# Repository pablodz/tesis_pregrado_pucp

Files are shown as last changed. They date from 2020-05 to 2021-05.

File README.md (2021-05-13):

# Tesis de Pregrado

[Spanish](https://github.com/ZurMaD/tesis_pregrado_pucp/):
- [T1-Download PDF](https://github.com/ZurMaD/tesis_pregrado_pucp/blob/master/Latex/trabajo-de-investigacion-1/main.pdf)
- [T2-Download PDF](https://github.com/ZurMaD/tesis_pregrado_pucp/blob/master/Latex/trabajo-de-investigacion-2/main.pdf)

## Ambiente de de desarrollo (MikTex+TeXStudio)



## License

<br />This work is licensed under a <a rel="license" href="http://creativecommons.org/licenses/by-nc/4.0/">Creative Commons Attribution-NonCommercial 4.0 International License</a>.

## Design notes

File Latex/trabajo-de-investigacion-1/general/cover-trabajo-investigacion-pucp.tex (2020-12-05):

%----------------------------------------------------------------------------------------
%	Carátula
%----------------------------------------------------------------------------------------
\clearpage{\pagestyle{empty}\cleardoublepage}
\begin{titlepage}
\begin{center}
 {\Large \bf PONTIFICIA UNIVERSIDAD CATÓLICA DEL PERÚ}\\
  \vspace{0.8 cm} 
  {\Large \bf FACULTAD DE CIENCIAS E INGENIERÍA}\\
  \vspace{1.75 cm}
 \begin{figure}[H]
    \centering
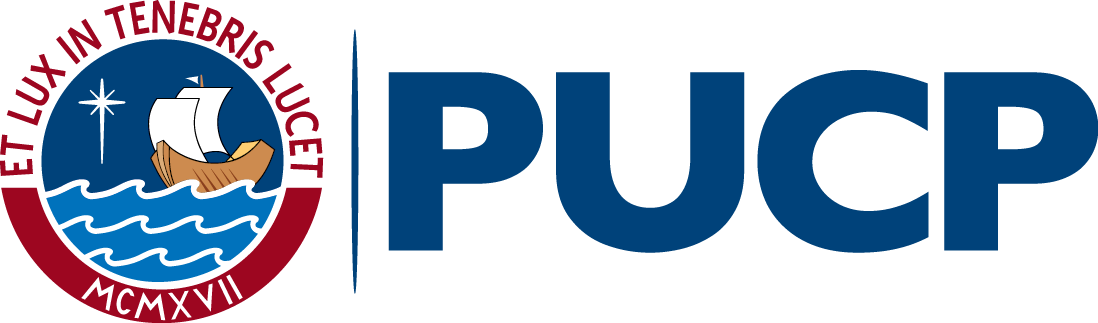
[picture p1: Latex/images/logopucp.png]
    
\end{figure}
  \vspace{0.25cm}

\title{Diseño conceptual de clasificadora y contadora de truchas arcoíris \textit{(Oncorhynchus mykiss)} de 10 a 20 centímetros para la crianza de truchas en la Laguna de Paucarcocha} % titulo de tu tesis para latex
{\Large \bf Diseño conceptual de clasificadora y contadora de truchas arcoíris \textit{(Oncorhynchus mykiss)} de 10 a 20 centímetros para la crianza de truchas en la Laguna de Paucarcocha}\\ % titulo de tu tesis para latex
\vspace{0.5cm}
{\Large \bf TRABAJO DE INVESTIGACIÓN PARA LA OBTENCIÓN DEL GRADO DE BACHILLER EN CIENCIAS CON MENCIÓN EN INGENIERÍA MECATRÓNICA}\\[1.5 cm]
{\large \bf AUTOR}\\[0.5cm]
{\large Pablo Remigio Díaz Vergara}\\[1.25 cm] % nombres del autor o autores
{\large \bf ASESOR}\\[0.5 cm] 
{\large Ing. Pedro Moises Crisóstomo Romero}\\[0.5 cm] % nombre del asesor
\vspace{1.75 cm}
{\large Lima, diciembre, 2019}

\end{center}
\end{titlepage}

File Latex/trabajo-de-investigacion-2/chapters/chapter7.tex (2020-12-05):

%----------------------------------------------------------------------------------------
%	Capítulo 6
%----------------------------------------------------------------------------------------

\pagestyle{myportland}
\doublespacing
%\pagenumbering{arabic}
\chapter[\quad\quad\quad\quad ----- Estimación de costos]{\\ Estimación de costos}
\thispagestyle{myportland}

La estimación de costos del sistema en su conjunto se calcula mediante la separación por rubros específicos. Dichos rubros son relacionados al diseño, manufactura, materiales y dispositivos de uso eléctrico y electrónico.
%% NUEVA SECCIÓN X.X
\section{Costos de diseño}

Este costo está relacionado con la actividad de ingeniería de diseño, se calcula mediante la multiplicación de horas empleadas por el tesista en la redacción, diseño conceptual y diseño de ingeniería con el sueldo mínimo que suele recibir un practicante pre-profesional en el Perú. Las horas empleadas son calculadas por el tesista, el costo es teórico y pretende dar cifras acordes al mercado. En la Tabla \ref{tab:costo de diseno de ingenieria} se detallan los costos asociados mencionados.

\begin{table}[H]
	\footnotesize\centering
	\caption{Costo de diseño de ingeniería.}
	\label{tab:costo de diseno de ingenieria}
	\begin{tabular}{lc|c|c|}
		\hline
		\multicolumn{4}{|c|}{\textbf{Costo de diseño de ingeniería}}  \\ \hline
		\multicolumn{1}{|c|}{\textbf{Concepto}} & \multicolumn{1}{c|}{\textbf{Horas}} & \multicolumn{1}{c|}{\textbf{Costo/hora (S/)}} & \multicolumn{1}{c|}{\textbf{Subtotal (S/)}} \\ \hline
		\multicolumn{1}{|l|}{Diseño conceptual del sistema} & 350 & 9.30 & 3255.00 \\ \hline
		\multicolumn{1}{|l|}{Diseño de ingeniería del sistema} & 350 & 9.30 & 3255.00 \\ \hline
		& & \textbf{Total (S/)} & \textbf{6510.00}  \\ \cline{3-4} 
	\end{tabular}
	\begin{myflushcenteraftertable}	
		Fuente: Elaboración propia.
	\end{myflushcenteraftertable}
\end{table}

%\multicolumn{1}{|l|}{Ensamble del sistema} & A & A & A \\ \hline
%\multicolumn{1}{|l|}{Pruebas del sistema} & A & A & A \\ \hline

%% NUEVA SECCIÓN X.X
\section{Costos de componentes}

Los componentes a considerar son los componentes eléctricos y electrónicos que se emplean para el funcionamiento correcto de la máquina. Los dispositivos son de importación por lo que se aplica un impuesto por importación y gastos de envios en 30\%, con dicha cifra se calcula el costo total. En la Tabla \ref{tab:costo de componentes electricos y electronicos} se exponen de forma detallada los costos unitarios de cada componentes y el total después de envíos e impuestos.

\begin{table}[H]
	\footnotesize\centering
	\caption{Costo de componentes eléctricos y electrónicos.}
	\label{tab:costo de componentes electricos y electronicos}
	\begin{tabular}{llc|c|c|}
		\hline
		\multicolumn{5}{|c|}{\textbf{Costo de componentes eléctricos y electrónicos}} \\ \hline
		\multicolumn{1}{|c|}{\textbf{Componente}} & \multicolumn{1}{c|}{\textbf{Modelo}} & \multicolumn{1}{c|}{\textbf{Costo Unitario (S/)}} & \multicolumn{1}{c|}{\textbf{Cantidad}} & \multicolumn{1}{c|}{\textbf{Subtotal (S/)}} \\ \hline
		\multicolumn{1}{|l|}{Motor a pasos}  & \multicolumn{1}{l|}{NEMA 34} & 78.98 & 2 & 157.96 \\ \hline
		\multicolumn{1}{|l|}{Driver de motor a pasos}  & \multicolumn{1}{l|}{DM860H} & 71.8 & 2 & 143.6 \\ \hline
		\multicolumn{1}{|l|}{Bomba de agua} & \multicolumn{1}{l|}{D03U-DK004X4} & 969.30 & 2 & 1938.6 \\ \hline
		\multicolumn{1}{|l|}{Electroválvula 4''} & \multicolumn{1}{l|}{CTB100} & 287.20 & 1 & 287.20 \\ \hline
		\multicolumn{1}{|l|}{Sensor de presión}  & \multicolumn{1}{l|}{WNK80MA} & 43.08 & 4 & 172.32 \\ \hline
		\multicolumn{1}{|l|}{Sensor infrarrojo}  & \multicolumn{1}{l|}{HD-DS25CM-3MM} & 7.00 & 1 & 7.00 \\ \hline
		\multicolumn{1}{|l|}{Cámara estéreo}  & \multicolumn{1}{l|}{OAK-D} & 475.41 & 1 & 475.41 \\ \hline
		\multicolumn{1}{|l|}{Cámara simple}  & \multicolumn{1}{l|}{OAK-1}& 355.41 & 1 & 355.41 \\ \hline
		\multicolumn{1}{|l|}{LED's de iluminación}  & \multicolumn{1}{l|}{PSH601A} & 17.23 & 1 & 17.23 \\ \hline
		\multicolumn{1}{|l|}{Microprocesador}   & \multicolumn{1}{l|}{Raspberry Pi 4B} & 197.45 & 1 & 197.45 \\ \hline
		\multicolumn{1}{|l|}{Indicador visual}  & \multicolumn{1}{l|}{HS-WS812B-16L-b} & 12.57 & 3 & 37.71 \\ \hline
		\multicolumn{1}{|l|}{Indicador sonoro}  & \multicolumn{1}{l|}{SE-B40} & 35.9 & 1 & 35.9 \\ \hline
		\multicolumn{1}{|l|}{Interruptor de emergencia}  & \multicolumn{1}{l|}{LAY5-JBPN1P} & 21.54 & 1 & 21.54 \\ \hline
		\multicolumn{1}{|l|}{Sensor de iluminación}  & \multicolumn{1}{l|}{-} & 21.36 & 1 & 21.36 \\ \hline
		\multicolumn{1}{|l|}{\begin{minipage}{\mythirdmaxsizeofcontenttable}\begin{myflushleftinsidetable}
					Interruptor de suministro de energía
		\end{myflushleftinsidetable}\end{minipage}}
		&
		\multicolumn{1}{l|}{HEIGHT S/C} & 53.85 & 1 & 53.85 \\ \hline
		\multicolumn{1}{|l|}{Fuente de alimentación}  & \multicolumn{1}{l|}{BNM-24V-500W} & 80.60 & 1 & 80.60 \\ \hline		
		\multicolumn{1}{|l|}{\begin{minipage}{\mythirdmaxsizeofcontenttable}\begin{myflushleftinsidetable}
					Convertidor de voltaje de conmutación
		\end{myflushleftinsidetable}\end{minipage}}
		&
		\multicolumn{1}{l|}{\begin{minipage}{\mythirdmaxsizeofcontenttable}\begin{myflushleftinsidetable}
				WMX-DSD24S1220 y WMX-DSD45S520
		\end{myflushleftinsidetable}\end{minipage}}
		 & 102.78 & 1 & 102.78 \\ \hline
		\multicolumn{1}{|l|}{Placa I2C generador PWM}  & \multicolumn{1}{l|}{PCA9685} & 53.67 & 1 & 53.67 \\ \hline
		\multicolumn{1}{|l|}{Cables} & \multicolumn{1}{l|}{-} & 20 & 1 & 20 \\ \hline
		\multicolumn{1}{|l|}{Activador tipo transistor}  & \multicolumn{1}{l|}{TPN2R304PL} & 0.36 & 4 & 1.44 \\ \hline
		&  &  & \textbf{Subtotal (S/)} & \textbf{5281.03} \\ \cline{4-5} 
		&  &  & \textbf{Impuestos (30\%)} & \textbf{1584.31} \\ \cline{4-5} 
		&  &  & \textbf{Total (S/)} & \textbf{6865.34} \\ \cline{4-5} 
	\end{tabular}
		\begin{myflushcenteraftertable}	
		Fuente: Elaboración propia. \\
		Tasa de cambio de USD a PEN: S/ 3.59.
	\end{myflushcenteraftertable}
\end{table}

%\multicolumn{1}{|l|}{Driver de bomba de agua} & \multicolumn{1}{l|}{B} & B & B & B \\ \hline

Entonces, el costo de todos los componentes sin ensamblar es de S/ 6865.34 incluyendo gastos de envío y traslado de la cantidad específicada en la Tabla \ref{tab:costo de componentes electricos y electronicos}. Este total no debe ser comparado con máquinas comerciales debido a que es el costo de producir una sola máquina y no de producir en lotes, además de no haber pasado por la etapa de prototipado que suele disminuir el precio y perfeccionar el sistema disminuyendo el costo.

%% NUEVA SECCIÓN X.X
\section{Costos de materiales}

Los materiales abarcan las planchas de metal a doblar, las tuberías de plásticos, los perfiles de metal a soldar, los tornillos y refuerzos del sistema. Dichos materiales son listados con su precio comercial actual en los mercados nacionales en la Tabla \ref{tab:costo de materiales estructurales y tuberias}.

\begin{table}[H]
	\footnotesize\centering
	\caption{Costo de materiales estructurales y tuberías}
	\label{tab:costo de materiales estructurales y tuberias}
	\begin{tabular}{llc|c|c|}
		\hline
		\multicolumn{5}{|c|}{\textbf{Costo}} \\ \hline
		\multicolumn{1}{|c|}{\textbf{Material}} & \multicolumn{1}{c|}{\textbf{Descripción}} & \multicolumn{1}{c|}{\textbf{Costo Unitario (S/)}} & \multicolumn{1}{c|}{\textbf{Cantidad}} & \multicolumn{1}{c|}{\textbf{Subtotal}} \\ \hline
		\multicolumn{1}{|l|}{AISI 316} & \multicolumn{1}{l|}{Tubo perfil cuadrado 20x20x5000 mm. (e=2 mm.)} & A & A & A \\ \hline
		\multicolumn{1}{|l|}{AISI 316} & \multicolumn{1}{l|}{Plancha 1x1220x2440 mm.} & 500 & 2 & 1000 \\ \hline
		\multicolumn{1}{|l|}{AISI 316} & \multicolumn{1}{l|}{Plancha 1.5x1220x2440 mm.} & 700 & 1 & 700 \\ \hline
		\multicolumn{1}{|l|}{AISI 316} & \multicolumn{1}{l|}{Plancha 2x1220x2440 mm.} & 850 & 1 & 850 \\ \hline		
		\multicolumn{1}{|l|}{Triplay} & \multicolumn{1}{l|}{Plancha 1x1220x2440 mm.} & 50 & 2 & 100 \\ \hline
		\multicolumn{1}{|l|}{PVC} & \multicolumn{1}{l|}{Tubo 4''x1000 mm.} & 10 & 1 & 10 \\ \hline
		\multicolumn{1}{|l|}{PVC} & \multicolumn{1}{l|}{Tubo 3''x1000 mm.} & 10 & 1 & 10 \\ \hline
		\multicolumn{1}{|l|}{PVC} & \multicolumn{1}{l|}{Tubo Reductor 4-3''} & 5 & 2 & 10 \\ \hline
		\multicolumn{1}{|l|}{PVC} & \multicolumn{1}{l|}{Codo 145 °C 4''} & 3 & 2 & 6 \\ \hline
		\multicolumn{1}{|l|}{PVC} & \multicolumn{1}{l|}{Codo Tipo Y 4''} & 3 & 1 & 3 \\ \hline
		\multicolumn{1}{|l|}{PVC} & \multicolumn{1}{l|}{Codo 90 °C 4''} & 2 & 8 & 16 \\ \hline
		\multicolumn{1}{|l|}{PVC} & \multicolumn{1}{l|}{Codo 145 °C 3''} & 2.5 & 2 & 5 \\ \hline
		\multicolumn{1}{|l|}{PVC} & \multicolumn{1}{l|}{Codo Tipo Y 3''} & 2.2 & 1 & 2.2 \\ \hline
		\multicolumn{1}{|l|}{PVC} & \multicolumn{1}{l|}{Codo 90 °C 3''} & 1.8 & 4 & 7.2 \\ \hline
		\multicolumn{1}{|l|}{AISI 316} & \multicolumn{1}{l|}{Tornillos M4x20} & 0.15 & 18 & 2.70 \\ \hline
		\multicolumn{1}{|l|}{AISI 316} & \multicolumn{1}{l|}{Tornillos M6x60} & 0.20 & 12 & 2.40 \\ \hline
		\multicolumn{1}{|l|}{AISI 316} & \multicolumn{1}{l|}{Tornillos M6x18} & 0.20 & 36 & 7.20 \\ \hline
		\multicolumn{1}{|l|}{AISI 316} & \multicolumn{1}{l|}{Tornillos M8x20} & 0.50 & 16 & 5 \\ \hline
		\multicolumn{1}{|l|}{AISI 316} & \multicolumn{1}{l|}{Tornillos M14x30} & 0.75 & 16 & 12 \\ \hline
		\multicolumn{1}{|l|}{AISI 316} & \multicolumn{1}{l|}{Perno en U 3''} & 0.29 & 2 & 0.58 \\ \hline
		\multicolumn{1}{|l|}{AISI 316} & \multicolumn{1}{l|}{Sujetador sensor infrarrojo} & 3 & 2 & 6 \\ \hline
		\multicolumn{1}{|l|}{Nylon} & \multicolumn{1}{l|}{Cuerdas de sujeción} & 5 & 1 & 5 \\ \hline		
		&  &  & \textbf{Total} & \textbf{2760.28} \\ \cline{4-5} 
	\end{tabular}
	\begin{myflushcenteraftertable}	
		Fuente: Elaboración propia.
	\end{myflushcenteraftertable}
\end{table}

El costo total por concepto de materiales se calcula en S/ 2760.28 y no se le agrega costo de envío ya que todos los materiales listados se pueden conseguir en el mercado nacional, entonces no es necesario ningún incremento en su costo total.

%% NUEVA SECCIÓN X.X
\section{Costos de manufactura}

Los costos de manufactura contemplados en esta sección abarcan únicamente los costos directos de mano de obra, los costos directos de los materiales fueron considerados en la anterior sección y los gastos generales de manufactura están considerados dentro del costo de mano de obra que se presenta en la Tabla debido a que se realiza los servicios por una empresa que brinda los servicios por separado.

\begin{table}[H]
	\footnotesize\centering
	\caption{Costo de manufactura.}
	\label{tab:costo de manufactura}
	\begin{tabular}{l|c|}
		\hline
		\multicolumn{2}{|c|}{\textbf{Costo de mano obra}}  \\ \hline
		\multicolumn{1}{|c|}{\textbf{Concepto}} & \multicolumn{1}{c|}{\textbf{Subtotal (S/)}} \\ \hline
		\multicolumn{1}{|l|}{Servicio de soldadura} & 200.00 \\ \hline
		\multicolumn{1}{|l|}{Servicio de corte láser} & 500.00 \\ \hline
		\multicolumn{1}{|l|}{Servicio de plegado} & 200.00 \\ \hline
		\multicolumn{1}{|l|}{Servicio de mecanizado} & 500.00 \\ \hline
		\multicolumn{1}{|l|}{\textbf{Total (S/)}} &  1400.00 \\ \hline
	\end{tabular}
	\begin{myflushcenteraftertable}	
		Fuente: Elaboración propia.
	\end{myflushcenteraftertable}
\end{table}

%% NUEVA SECCIÓN X.X
\section{Costos total del sistema}

La suma de costos del sistema con las características que se explican en cada sección se calcula alrededor de S/17600.00 ($\approx$\$ 4900.00) que incluye costos de diseño y ensamblaje, componentes eléctricos y electrónicos, materiales y manufactura de un sistema de clasificación y conteo de truchas.

\begin{table}[H]
	\footnotesize\centering
	\caption{Costo total del sistema.}
	\label{tab:costo total del sistema}
	\begin{tabular}{lc|c|c|}
		\hline
		\multicolumn{4}{|c|}{\textbf{Costo del sistema}}  \\ \hline
		\multicolumn{1}{|c|}{\textbf{Concepto}} & \multicolumn{1}{c|}{\textbf{Costo (S/)}} & \multicolumn{1}{c|}{\textbf{Impuestos+Envío (S/)}} & \multicolumn{1}{c|}{\textbf{Subtotal (S/)}} \\ \hline
		\multicolumn{1}{|l|}{Costo de diseño y ensamblaje} & 6510.00 & -- & 6510.00 \\ \hline
		\multicolumn{1}{|l|}{Costo de componentes} & 5281.03 & 1584.31 & 6865.34 \\ \hline
		\multicolumn{1}{|l|}{Costo de materiales} & 2760.28 & -- & 2760.28 \\ \hline
		\multicolumn{1}{|l|}{Costo de manufactura} & 1400.00 & -- & 1400.00 \\ \hline
		& & \textbf{Total (S/)} & \textbf{17535.62}  \\ \cline{3-4} 
	\end{tabular}
	\begin{myflushcenteraftertable}	
		Fuente: Elaboración propia.
	\end{myflushcenteraftertable}
\end{table}

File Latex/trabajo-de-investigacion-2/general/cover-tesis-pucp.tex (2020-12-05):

%----------------------------------------------------------------------------------------
%	Carátula
%----------------------------------------------------------------------------------------
\clearpage{\pagestyle{empty}\cleardoublepage}
\begin{titlepage}
	\begin{center}
		{\Large \bf PONTIFICIA UNIVERSIDAD CATÓLICA DEL PERÚ}\\
		\vspace{0.8 cm} 
		{\Large \bf FACULTAD DE CIENCIAS E INGENIERÍA}\\
		\vspace{1.75 cm}
		\begin{figure}[H]
			\centering
			
		\end{figure}
		\vspace{0.25cm}
		
		\title{Diseño conceptual de clasificadora y contadora de truchas arcoíris \textit{(Oncorhynchus mykiss)} de 10 a 20 centímetros para la crianza de truchas en la Laguna de Paucarcocha} % titulo de tu tesis para latex
		{\Large \bf Diseño integral de clasificadora y contadora de truchas arcoíris \textit{(Oncorhynchus mykiss)} de 10 a 20 centímetros para la crianza de truchas en la Laguna de Paucarcocha}\\ % titulo de tu tesis para latex
		\vspace{0.5cm}
		{\Large \bf TESIS PARA OPTAR POR EL TÍTULO DE BACHILLER EN CIENCIAS CON MENCIÓN EN INGENIERÍA MECATRÓNICA}\\[1.5 cm]
		{\large \bf AUTOR}\\[0.5cm]
		{\large Pablo Remigio Díaz Vergara}\\[1.5 cm] % nombres del autor o autores
		{\large \bf ASESOR}\\[0.5 cm] 
		{\large Ing. Pedro Moises Crisóstomo Romero}\\[0.5 cm] % nombre del asesor
		\vspace{2.0 cm}
		{\large Lima, diciembre, 2020}
		
	\end{center}
\end{titlepage}

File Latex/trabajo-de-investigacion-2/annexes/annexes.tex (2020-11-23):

%----------------------------------------------------------------------------------------
%	Anexos
%----------------------------------------------------------------------------------------

\newpage
%\appendix
\renewcommand{\appendixname}{Anexos}%
\chapter*{\appendixname}

HD-DS25CM-3MM
\href{https://www.adafruit.com/product/2167}{Enlace}
QT50CM
\href{https://www.adafruit.com/product/2168}{Enlace}
GP2Y0A21YK0F
\href{https://www.adafruit.com/product/164}{Enlace}
OAK-D
\href{https://www.arducam.com/oak-opencv-ai-kit-camera/}{Enlace}
B0263
\href{https://www.arducam.com/product/arducam-1mp-stereo-camera-for-raspberry-pi-nvidia-jetson-nano-xavier-nx-dual-ov9281-monochrome-global-shutter-camera-module/}{Enlace}
B0204
\href{https://www.arducam.com/product/b0204-arducam-2mp-global-shutter-ov2311-monochrome-camera-modules-for-raspberry-pi/}{Enlace}
B0249
\href{https://www.arducam.com/product/b0242-arducam-imx477-hq-camera/}{Enlace}
Alvium 1800-U-500m
\href{https://www.edmundoptics.com/p/allied-vision-alvium-1800-u-500m-125-50mp-usb-31-monochrome-camera-board-level/42347/}{Enlace}
CMT-8MP-IMX219-M366
\href{https://github.com/rellimmot/Sony-IMX219-Raspberry-Pi-V2-CMOS}{Enlace}
RPI4B-4GB
\href{https://www.raspberrypi.org/documentation/hardware/raspberrypi/bcm2711/rpi_DATA_2711_1p0_preliminary.pdf
E13446_Tinker_Board_S_UM_WEB}{Enlace}
\href{https://dlcdnets.asus.com/pub/ASUS/mb/Embedded_IPC/TinkerBoard_S/E13446_Tinker_Board_S_UM_WEB.pdf
UFSUB64_E}{Enlace}
\href{https://www.helios.de/web/EN/products/dtsheets_ub64.html}{Enlace}

INDICADOR LUZ NSSW108T NSSW100DT NFSL757GT-V1
\href{https://www.alibaba.com/product-detail/DC24V-smd-lm301b-3030-led-flexible_60785330755.html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}{Enlace}
\href{https://www.alibaba.com/product-detail/Ultra-Bright-SMD-5050-DC-12V_1600057430279.html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}{Enlace}

INDICADOR SONORO SE-B40 SBN151 HMK-69TM
\href{https://spanish.alibaba.com/product-detail/wholesale-cheap-4-5-6-5-inch-2-way-car-audio-speaker-with-tweeter-car-speakers-coaxial-stereo-speaker-for-car-60848556085.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}{Enlace}
\href{https://spanish.alibaba.com/product-detail/1000-watt-powerful-blue-painting-frame-speakers-subwoofer-with-dc-12v-15-inch-speakers-60601667315.html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}{Enlace}
\href{https://spanish.alibaba.com/product-detail/black-12v-car-speakers-6-9-car-speaker-coaxial-car-speaker-hmk-69tm--60292070214.html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}{Enlace}

LED ILUMINACION HS-WS812B-16L-b HS-SK6812-24L-c HS-WS2812B-R16
\href{https://spanish.alibaba.com/product-detail/ws2812b-programable-pixel-led-ring-5v-16leds-rgb-led-ring-lights-60856221694.html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}{Enlace}
\href{https://spanish.alibaba.com/product-detail/addressable-circle-sk6812-ic-built-in-1-8-12-16-24-32-48-60-82-93-rgbw-leds-ring-light-62075774615.html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}{Enlace}
\href{https://spanish.alibaba.com/product-detail/ws2812b-addressable-16-leds-smd5050-rgb-led-angel-eyes-ring-pcb-board-light-1600063580610.html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}{Enlace}

INTERRUPTOR EMERGENCIA LAY5-BS542 LAY5-JBPN1P
\href{https://www.alibaba.com/product-detail/LAY5-BS542-40mm-mushroom-head-emergency_724522258.html}{Enlace}
\href{https://www.alibaba.com/product-detail/LAY5-JBPN1P-single-hole-Button-box_62013768277.html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}{Enlace}
\href{https://www.alibaba.com/product-detail/LAY5-B174H29-push-button-switch-push_60627351782.html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}{Enlace}

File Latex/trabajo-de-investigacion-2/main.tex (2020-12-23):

\include{general/config} % Set page configurations

\begin{document}
	\include{general/cover-tesis-pucp} % Carátula para Tesis
	%\include{general/cover-trabajo-investigacion-pucp}% Carátula para Trabajos de investigación
	\include{general/summary} % Starts roman counter
	\include{general/gratitude} % Agradecimientos (opcional)
	\include{general/table-of-content} % Starts arabic counter
	\include{chapters/before-chapters} % Configuración de páginas
	%\include{chapters/chapter1} % TFC1
	%\include{chapters/chapter2} % TFC1
	%\include{chapters/chapter3} % TFC1	
	\include{general/introduction} 
	\include{chapters/chapter4}
	\include{chapters/chapter5}
	\include{chapters/chapter6}
	\include{chapters/chapter7}
	\include{general/conclusions}
	\include{general/recommendations}
	\include{general/bibliography}
	\include{chapters/after-chapters} % Configuración de páginas
	%\include{annexes/cover-tesis-annexes}
	%\include{annexes/cover-trabajo-investigacion-annexes}% Carátula para Trabajos de investigación
	%\include{annexes/annexes} % No se puede adjuntar pdfs
\end{document}

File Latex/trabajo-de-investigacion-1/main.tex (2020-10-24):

\include{general/config} % Set page configurations

\begin{document}
	%\include{general/cover-tesis-pucp} % Carátula para Tesis
	\include{general/cover-trabajo-investigacion-pucp}% Carátula para Trabajos de investigación
	\include{general/summary} % Starts roman counter
	\include{general/introduction} 
	%\include{general/gratitude} % Agradecimientos (opcional)
	\include{general/table-of-content} % Starts arabic counter
	\include{chapters/before-chapters} % Configuración de páginas
	\include{chapters/chapter1}
	%\include{chapters/chapter2}
	\include{chapters/chapter3}
	\include{general/conclusions}
	%\include{general/recommendations}
	\include{general/bibliography}
	\include{chapters/after-chapters} % Configuración de páginas
	%\include{general/annexes}
\end{document}

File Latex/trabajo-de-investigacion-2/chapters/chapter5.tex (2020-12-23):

%----------------------------------------------------------------------------------------
%	Capítulo 5 
%----------------------------------------------------------------------------------------

\pagestyle{myportland}
%\pagenumbering{arabic}
\doublespacing
\chapter[\quad\quad\quad\quad ----- Diseño mecatrónico integral]{\\ Diseño mecatrónico integral}
\thispagestyle{myportland}

%%%%%%%%%%%%%%%%%%%%%%%%%%%%%%%%%%%%%%%%%%%%%%%%%%%%%%%%%%%%%%
%%%%%                                                    %%%%%
%%%%%             DISEÑO MECATRÓNICO EN SÍ               %%%%%
%%%%%                                                    %%%%%
%%%%%%%%%%%%%%%%%%%%%%%%%%%%%%%%%%%%%%%%%%%%%%%%%%%%%%%%%%%%%%

En este capítulo se realiza el diseño de ingeniería del sistema que abarca la selección de componentes, su distribución eléctrica, electrónica y física. Los cálculos y dimensionamiento asociado a las partes del sistema se desarrollan en este capítulo. Además se realiza una comparación técnica de los componentes acorde a los propósitos de la máquina que finaliza con la selección del componente, mecanismo o algoritmo más apropiado.

\begin{myfigure}[H]
	\footnotesize\centering
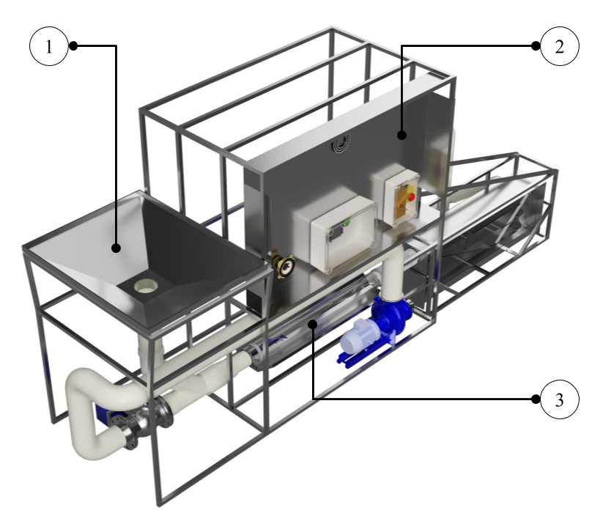
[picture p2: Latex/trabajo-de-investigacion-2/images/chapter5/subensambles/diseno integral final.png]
	
	\caption{Diseño integral de la máquina de clasificación y conteo de truchas.}
	\begin{myflushcenter}
		Leyenda: (1) subsistema de recepción, distribución y traslado de truchas; (2) subsistema de control e interacción con el usuario; (3) subsistema de procesamiento de imágenes.\\
		Fuente: Elaboración propia
	\end{myflushcenter}
	\label{fig:diseno integral}
\end{myfigure}

\vspace{-2.0em}

%% NUEVA SECCIÓN X.X
\section{Descripción del sistema integral}
\label{ssec:descripcion del sistema integral}

Respecto al diseño conceptual, existen algunas modificaciones en los tipos de dispositivos por características técnicas detectadas en el desarrollo de ingeniería del sistema: el cambio del servomotor por un mecanismo de motor a pasos con leva-seguidor que disminuye el desgaste por el sentido de giro; la batería ya no es parte del sistema, el operario debe suministrar la energía necesaria; el adicional de una cámara para el seguimiento de la trayectoria de truchas en el mecanismo de distribución; la variación de el uso de un microcontrolador a microprocesador debido a la potencia computacional requerida; el cambio de bombas sumergibles a bombas de agua por la eficiencia y potencia necesaria en el proyecto\footnote{El precio de las bombas sumergibles sube considerablemente correspondiente a la potencia requerida.}; remoción de la reja al inicio accionada por un motor debido al coste de implementación y reemplazo con un tapón de plástico; cambio de nombre del interruptor de tipo hongo a interruptor de suministro de energía; aumento del máximo peso admisible según requisito a 400 kg. debido al empleo de plataformas flotantes de alta capacidad de flotación en lugar de su uso en botes de 3 metros de largo.

%\textcolor{blue}{[BORRADOR] INGRESAR AQUÍ CAMBIOS REALIZADOS [/BORRADOR]}\\

La máquina clasificadora y contadora de truchas (CCT), y su sistema respectivo tienen como función principal recepcionar truchas mediante una tolva, procesar la clasificación, conteo y distribución hacia tres jaulas flotantes en medio de la Laguna de Paucarcocha.\footnote{\cite{DiazVergara2020}} La máquina se sitúa sobre el agua y es empleada por un operario, que se encarga de extraer truchas con una sacadera telescópica\footnote{También llamada cal-cal.}. En las siguientes páginas se analizan dos puntos generales concernientes al sistema: arquitectura de hardware y la selección de materiales de fabricación por subsistema.

%% NUEVO SUBSECCION X.X.X
\subsection{Arquitectura de hardware}

En la Figura \ref{fig:arquitectura de hardware del sistema} se muestra la propuesta de arquitectura de hardware. Esta arquitectura muestra las entradas de energía del sistema, su redistribución a cada componente, el control asociado a cada pieza mediante el subsistema de control y los protocolos o energía asociado a cada par de bloques. Además, el tipo de conexión se detalla en la leyenda. 

\begin{myfigure}[H]
	\footnotesize\centering
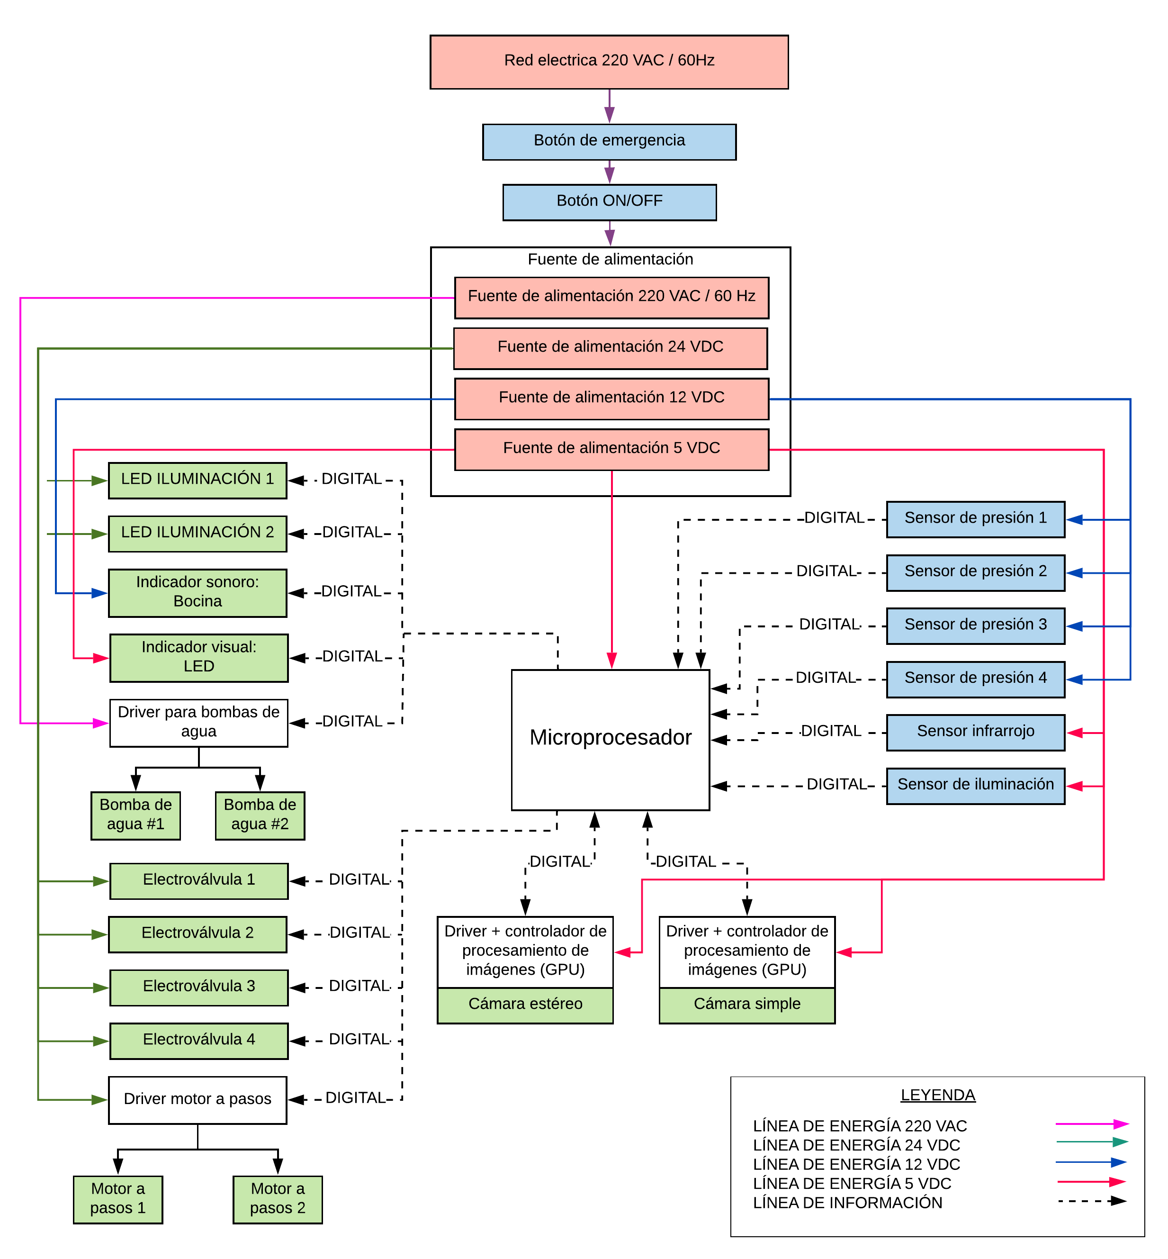
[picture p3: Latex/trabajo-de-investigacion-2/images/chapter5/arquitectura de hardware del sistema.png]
	
	\caption{Arquitectura de hardware del sistema}
	\begin{myflushcenter}
		Fuente: Elaboración propia.
	\end{myflushcenter}
	\label{fig:arquitectura de hardware del sistema}
\end{myfigure}

%% NUEVO SUBSECCION X.X.X
\subsection{Selección de materiales de fabricación}
\label{sssec:seleccion de materiales de fabricacion}

Cada subsistema posee mecanismos que se rigen por un material en general, esto incluye a las partes principales del subsistema. Sin embargo, no considera el material de tornillos, ajustes o dispositivos similares. Existen así mismos requisitos que se pueden generalizar para todos los subsistemas por el entorno de trabajo a la que estará sometida la máquina detallados en la \textit{"Lista de requerimientos"} \footnote{\cite{DiazVergara2020}.}. Basado en dichas demandas, cada subsistema es analizado y presentado con dos alternativas posibles de materiales. Consecuentemente, se elige un material decisivo para ser empleado bajo el sustento técnico que se explicará en los siguientes párrafos.\\

%\begin{itemize}[\null]

\textbf{Subsistema de recepción y traslado de truchas:} Cuenta con dos mecanismos; recepción de truchas y tuberías de traslado. El primero debe recepcionar a las truchas y dirigirlas al mecanismo de tuberías. El segundo debe trasladar a las truchas de un punto a otro de la máquina mediante las tuberías. En la Tabla \ref{tab:tabla comparativa de propiedades entre aluminio vs acero inoxidable} se comparan técnicamente las propiedades mecánicas, térmicas y ópticas de dos materiales.

\begin{mytable}[H]
	\footnotesize\centering
	\caption{Tabla comparativa de propiedades entre $Aluminio$ vs $Acero \quad Inoxidable$}
	\label{tab:tabla comparativa de propiedades entre aluminio vs acero inoxidable}
	\begin{tabular}{|l|c|c|}
		\hline
		\multicolumn{1}{|c|}{\textbf{Propiedad}} & \textbf{Aluminio} & \textbf{Acero Inoxidable} \\ \hline
		Módulo de Young ($GPa$) & 69 & 200 \\ \hline
		Esfuerzo de fatiga $Y$ ($MPa$) & 58-110 & 210-430 \\ \hline
		Resistencia a la tracción ($MPa$) & 130-410 & 520-1180 \\ \hline
		Temperatura máxima mecánica (°$C$) & 650 & 590 \\ \hline
		Conductividad térmica ($W/m-K$) & 170 & 15 \\ \hline
		Expansión térmica (${\mu}m/m-K$) & 24 & 16 \\ \hline
		Conductividad eléctrica ($\%$) & 43 & 2.3 \\ \hline
		Densidad ($g/cm^3$) & 2.7 & 7.9 \\ \hline
	\end{tabular}
	\begin{myflushcenteraftertable}
		*Terminología técnica de los materiales: Aluminio 6061, Acero Inoxidable AISI 306 .\\		
		Fuente: \cite{MakeItFrom2020}.
	\end{myflushcenteraftertable}
\end{mytable}

El material escogido es Aluminio 6061 por tener una densidad menor, facilidad de realizar juntas de soldadura, y aunque tenga menor resistencia mecánica cumple con los requerimientos mínimos asociados al subsistema mencionado.\\

\textbf{Subsistema de procesamiento de imágenes:} Cuenta con los mecanismos de tuberías y juego de espejos. El primero debe brindar a la cámara suficiente transparencia para obtener una fotografía adecuada. El segundo debe brindar a la cámara más perfiles del cuerpo que es trasladado por la tubería. En la Tabla \ref{tab:tabla comparativa de propiedades entre pmma vs pvdf vs petg} se compara técnicamente las propiedades mecánicas, térmicas y ópticas de tres materiales.

\begin{mytable}[H]
	\footnotesize\centering
	\caption{Tabla comparativa de propiedades entre $PMMA$, $PVDF$ y $PETG$}
	\label{tab:tabla comparativa de propiedades entre pmma vs pvdf vs petg}
	\begin{tabular}{|l|c|c|c|}
		\hline
		\multicolumn{1}{|c|}{\textbf{Propiedad}} & \multicolumn{1}{c|}{\textbf{PMMA}} & \textbf{PVDF}& \textbf{PETG} \\ \hline
		Resistencia al impacto: con muescas ($J/m$) & 74 & 180 & 77  \\ \hline
		Expansión térmica (${\mu}m/m-K$)  & 76 & 120 & 68 \\ \hline
		Densidad ($g/cm^3$) & 1.2 & 1.8  & 1.3 \\ \hline
		Resistencia al peso  & 32 & 20 & 25 \\ \hline
		Alargamiento a la rotura ($ \% $) & 4 & 49 & 53 \\ \hline
		Incidencia de luz trasmitida ($ \% $) & 92 & - & - \\ \hline
		Índice de refracción & 1.5 & 1.4 & 1.6\\ \hline			
	\end{tabular}
	\begin{myflushcenteraftertable}
		*Terminología técnica de los materiales: Polimetilmetacrilato (Acrílico)(PMMA), Fluoruro de polivinilideno (PVDF), Tereftalato de polietileno modificado con glicol (PETG).\\		
		Fuente: \cite{Brydson1999,Berins1991,Harper2000,MakeItFrom2020}.
	\end{myflushcenteraftertable}
\end{mytable}

Tanto el PMMA como el PETG tienen menores propiedades mecánicas que PVDF, pero en cuanto a densidad los materiales mencionados son más livianos comparados con el PVDF. En cuanto a las propiedades ópticas, el PMMA tiene un índice de refracción mayor que el PVDF pero menor que el PETG. Sin embargo, la el PMMA es el material más usado en propósitos ópticos comparado con los otros materiales mencionados. El PMMA transparente se puede encontrar en el mercado nacional e internacional por lo que se opta por este material para el subsistema mencionado. En el caso del juego de espejos, las propiedades ópticas son primordiales, por lo que se escoge PMMA.\\

\textbf{Subsistema de procesamiento de suministro de energía y subsistema de control e interacción con el usuario:} Los materiales son propios de los dispositivos electrónicos comerciales dependientes de la tecnología que se selecciona, por lo que se omite una clasificación de materiales en estos subsistemas.\\

%\textbf{:} Los materiales son propios de los dispositivos que serán adquiridos.

\textbf{Subsistema de flotación:} Cuenta con dos mecanismos; armadura y flotadores. El primero debe funcionar como esqueleto para los otros subsistemas y del mismo. El segundo debe mantener el sistema a flote. En la Tabla \ref{tab:tabla comparativa de propiedades entre hdpe vs pvcu} se compara técnicamente las propiedades mecánicas, térmicas y ópticas de dos materiales.

\begin{mytable}[H]
	\footnotesize\centering
	\caption{Tabla comparativa de propiedades entre $HDPE$ vs $PVC-U$}
	\label{tab:tabla comparativa de propiedades entre hdpe vs pvcu}
	\begin{tabular}{|l|c|c|}
		\hline
		\multicolumn{1}{|c|}{\textbf{Propiedad}} & \textbf{HDPE} & \textbf{PVC-U} \\ \hline
		Densidad ($g/cm^3$) & 1.0-1.3 & 1.4 \\ \hline
		Elongación a rotura ($\%$) & 2.5-100 & 58 \\ \hline
		Resistencia al impacto ($J/m$) & 50-260 & 360 \\ \hline
		Resistencia al peso: Flexión & 19-32 & 20 \\ \hline
		Resistencia a la tracción ($MPa$) & 24-80 & 47 \\ \hline
	\end{tabular}
	\begin{myflushcenteraftertable}
		*Terminología técnica de los materiales: Polietileno de alta densidad (HDPE), Cloruro de polivinilo no plastificado (Rígido) (uPVC, PVC-U)\\		
		Fuente: \cite{Brydson1999,Berins1991,Harper2000,MakeItFrom2020}.
	\end{myflushcenteraftertable}
\end{mytable}

En los flotadores es crucial las propiedades mecánicas, ya que en caso de falla puede hundir todo el sistema. La búsqueda de un material con baja densidad, alta resistencia a la tracción, impacto y al peso determinan el material escogido como HDPE. Además dicho material es comercializado nacionalmente e internacionalmente. De forma similar, la armadura debe poseer buenas propiedades mecánicas y por eso se selecciona Acero Inoxidable.\\

%\end{itemize}

Finalmente, en las Tablas \ref{tab:tabla comparativa de propiedades entre aluminio vs acero inoxidable}, \ref{tab:tabla comparativa de propiedades entre pmma vs pvdf vs petg} y \ref{tab:tabla comparativa de propiedades entre hdpe vs pvcu} se comparan diversos materiales para el correspondiente subsistema. Los materiales de fabricación finales para cada subsistema se muestran en la Tabla \ref{tab:materiales de fabricacion por subsistema}, fueron seleccionados por su superioridad en las propiedades técnicas que son valoradas en este proyecto. 

\begin{savenotes}
	\begin{mytable}[H]
		\footnotesize\centering
		\caption{Materiales de fabricación por subsistema}
		\label{tab:materiales de fabricacion por subsistema}
		\begin{tabular}{|l|c|c|}
			\hline
			\multicolumn{1}{|c|}{\textbf{Subsistema}} & \multicolumn{1}{c|}{\textbf{Mecanismo}} & \textbf{Material} \\ \hline
			Recepción y traslado de truchas      & Recepción de truchas   & Aluminio  \\ \hline
			Recepción y traslado de truchas      & Tuberías de traslado   & PVC-U    \\ \hline
			Procesamiento de imágenes            & Tubería                & PMMA  \\ \hline
			Procesamiento de imágenes            & Juego de espejos       & PMMA  \\ \hline
			Suministro de energía                & \multicolumn{1}{c|}{-} & -    \\ \hline
			Control e interacción con el usuario & \multicolumn{1}{c|}{-} & -  \\ \hline
			Flotación                            & Armadura               & Acero Inoxidable \\ \hline
			Flotación                            & Flotadores             & HDPE  \\ \hline
		\end{tabular}
		\begin{myflushcenteraftertable}
		*Terminología técnica de los materiales: Cloruro de polivinilo no plastificado (Rígido) (uPVC, PVC-U), Polimetilmetacrilato ISO 24026-1:2020\footnote{\href{https://www.iso.org/standard/77547.html}{Estándar ISO detallado}. Antecesor: 8257-1:1998. Estándar ASTM: D788-96} (Acrílico) (PMMA), Polietileno de alta densidad (HDPE), Acero Inoxidable AISI 306 , Aluminio 6061 (AL), Fluoruro de polivinilideno (PVDF).\\	
		Fuente: Elaboración propia.
		\end{myflushcenteraftertable}
	\end{mytable}
\end{savenotes}

%% NUEVA SECCIÓN X.X
\section{Repositorios de código fuente}
\label{ssec:repositorio de codigo fuente}

Los códigos de los sistemas, algoritmos y otros se almacenan de forma ordenada en repositorios que permiten el versionado, descentralización y disponibilidad de la información para poder reproducir, editar y mejorar los resultados por otras personas. En la Tabla

\begin{mytable}[H]
	\footnotesize\centering
	\caption{Lista de planos de subensamble.}
	\label{tab:lista de repositorios}
	\begin{tabular}{|l|l|l|}
		\hline
		\multicolumn{1}{|c|}{\textbf{Descripción}} & \multicolumn{1}{c|}{\textbf{Enlace}} & \multicolumn{1}{c|}{\textbf{Demo}} \\ \hline
		\textbf{Plantilla de tesis \LaTeX} & \href{https://github.com/ZurMaD/plantilla_tesis_pucp}{Github} & \href{https://github.com/ZurMaD/plantilla_tesis_pucp/blob/master/plantilla/main.pdf}{PDF} \\ \hline
		\textbf{Presente tesis de pregrado} & \href{https://github.com/ZurMaD/tesis_pregrado_pucp}{Github} & \href{https://github.com/ZurMaD/tesis_pregrado_pucp/blob/master/Latex/trabajo-de-investigacion-2/main.pdf}{PDF}  \\ \hline
		\textbf{Datasets de peces ($\approx$10GB)} & \href{https://github.com/DZPeru/fish-datasets}{Github} & -- \\ \hline		
		\textbf{Algoritmo de medición} & \href{https://github.com/DZPeru/fish-classifier}{Github} & --\\ \hline
		\textbf{Algoritmo de detección y conteo basado en YOLOv3} & \href{https://github.com/DZPeru/fishv3}{Github-Fishv3} & \href{https://fishv3.herokuapp.com/}{Demo-Web} \\ \hline 
		\textbf{Algoritmo de detección y conteo basado en YOLOv4} & \href{https://github.com/DZPeru/fishv4}{Github-Fishv4} & \href{https://fishv4.herokuapp.com/}{Demo-Web}\\ \hline 
		\textbf{Visualización de capas de YOLOv3} & -- & \href{https://netron.app/?url=https://raw.githubusercontent.com/DZPeru/fishv3/master/fishv3/fish_test.cfg}{Visualizador}\\ \hline 
		\textbf{Visualización de capas de YOLOv4} & -- & \href{https://netron.app/?url=https://raw.githubusercontent.com/DZPeru/fishv4/main/fishv4/fish_test.cfg}{Visualizador}\\ \hline 
		\textbf{Prototipo de aplicativo móvil} & -- & \href{https://bit.ly/3ko1nG0}{FigmaDemo}\\ \hline
		\textbf{Simulaciones estructurales} & \href{https://bit.ly/3ohX3ui}{Github} & -- \\ \hline		
	\end{tabular}
	\begin{myflushcenteraftertable}	
		Fuente: Elaboración propia.
	\end{myflushcenteraftertable}
\end{mytable}

\vspace{-2.0em}

%% NUEVA SECCIÓN X.X
\section{Planos del sistema}
\label{ssec:planos del sistema}

Los planos permiten visualizar el sistema de una forma en particular dependiendo del tipo de plano. El código asociado a cada plano indica el tipo de plano, su nivel respecto a la estructura general: ensamble, subensamble o despiece, y el tamaño de página usado para dicho plano. En las Tablas \ref{tab:lista de planos de ensamble y subensamble} y \ref{tab:lista de planos de subensamble} se detalla el código junto con la descripción. Dónde: \textit{E} es Ensamble, \textit{SE} es Subensamble, \textit{D} es despiece, los dígitos seguidos son alfanuméricos que van del 0 a la Z y es su agrupación es similar a la organización en cascada, y finalmente el tamaño de página.\footnote{Por ejemplo: D4587-A3 sería un despiece para el componente que pertenece al subensamble 4000, dentro del dispositivo 0500 y 0080. Además de ser el sétimo componente dentro del dispositivo.}

\vspace{-2.0 em}
%% NUEVO SUBSECCION X.X.X
\subsection{Lista de planos de ensamble}

El plano de ensamble presenta una visión de los diferentes componentes, cómo son las juntas, incluye un listado de componentes y se proporcionan características técnicas como el  tipo de material y cantidad de componentes similares.\footnote{Adaptado de \cite{Goetsch2010}} En la Tabla \ref{tab:lista de planos de ensamble y subensamble} se muestra la lista de planos de ensamble, subensambles y subsubensambles.

\begin{mytable}[H]
	\footnotesize\centering
	\caption{Lista de planos de ensamble y subensamble sistema.}
	\label{tab:lista de planos de ensamble y subensamble}
	\begin{tabular}{|l|l|}
		\hline
		\multicolumn{1}{|c|}{\textbf{Código de Plano}} & \multicolumn{1}{c|}{\textbf{Descripción}} \\ \hline
		\textbf{E1000-A0}         & Ensamble total  \\ \hline
		\textbf{SE1100-A3}        & Subsistema de recepción de truchas  \\ \hline
		\textbf{SE1200-A2}        & Subsistema de distribución de truchas \\ \hline
		\textbf{SE1300-A0}        & Subsistema de traslado de truchas \\ \hline
		\textbf{SE1400-A0}        & Subsistema de procesamiento de imágenes \\ \hline
		\textbf{SE1500-A2}        & Subsistema de control e interacción con el usuario\\ \hline
		\textbf{SE1600-A3}         & Estructura de soporte  \\ \hline
		\textbf{SSE1110-A3}        & Tolva de recepción \\ \hline
		\textbf{SSE1510-A3}        & Panel de control - Caja de control 1\\ \hline
		\textbf{SSE1520-A3}        & Panel de control - Caja de control 2\\ \hline
	\end{tabular}
	\begin{myflushcenteraftertable}	
		Fuente: Elaboración propia.
	\end{myflushcenteraftertable}
\end{mytable}

\vspace{-2.0 em}
%% NUEVO SUBSECCION X.X.X
\subsection{Plano de despiece}

El plano de despiece presenta las características técnicas de cada pieza: muestra dimensiones para poder fabricar la pieza.\footnote{En el presente trabajo se administran, además, subensambles con la finalidad de brindar mayor detalle a cada componente.} En la Tabla \ref{tab:lista de planos de subensamble} se muestra la lista de planos de despiece. 

\begin{mytable}[H]
	\footnotesize\centering
	\caption{Lista de planos de subensamble.}
	\label{tab:lista de planos de subensamble}
	\begin{tabular}{|c|l|}
		\hline
		\multicolumn{1}{|c|}{\textbf{Código de Plano}} & \multicolumn{1}{c|}{\textbf{Descripción}} \\ \hline
		\textbf{D1120-A1}         & Tolva de recepción - Borde \\ \hline
		\textbf{D1130-A3}         & Tolva de recepción - Base de salida \\ \hline
		\textbf{D1211-A1}         & Distribuidora 1:3 - Pared A \\ \hline
		\textbf{D1212-A1}         & Distribuidora 1:3 - Pared B \\ \hline
		\textbf{D1213-A3}         & Distribuidora 1:3 - Tapa de distribuidora \\ \hline
		\textbf{D1214-A3}         & Distribuidora 1:3 - Leva de distribuidora \\ \hline
		\textbf{D1215-A3}         & Distribuidora 1:3 - Lengüeta de salida de tubería \\ \hline
		\textbf{D1216-A3}         & Distribuidora 1:3 - Lengüeta de soporte de servomotor 1 \\ \hline
		\textbf{D1217-A3}         & Distribuidora 1:3 - Lengüeta de soporte de servomotor 2 \\ \hline 
		\textbf{D1218-A3}         & Distribuidora 1:3 - Compuerta mecánica \\ \hline 
		\textbf{D1311-A3}         & Tuberías - Adaptador de entrada de bomba de agua \\ \hline 
		\textbf{D1312-A3}         & Tuberías - Adaptador de salida de bomba de agua \\ \hline 
		\textbf{D1313-A3}         & Tuberías - Adaptador de electroválvula\\ \hline
		\textbf{D1413-A3}         & Procesamiento de imágenes - Soporte de cámara estéreo \\ \hline
		\textbf{D1414-A2}         & Procesamiento de imágenes - Soporte de espejos \\ \hline
		\textbf{D1501-A3}         & Panel de control - Soporte \\ \hline
	\end{tabular}
	\begin{myflushcenteraftertable}	
		Fuente: Elaboración propia.
	\end{myflushcenteraftertable}
\end{mytable}

\vspace{-2.0 em}

%----------------------------------------------------------------------------------------
%	Capítulo 5 
%----------------------------------------------------------------------------------------
%\pagestyle{myportland}
%\pagenumbering{arabic}
%\doublespacing
%\chapter[\quad\quad\quad\quad ----- Diseño de subsistema de flotación]{\\ Diseño de subsistema de flotación}
%\thispagestyle{myportland}
%\label{ssec:diseno de subsistema de flotacion}

\section{Subsistema de flotación}

Luego de definir en las secciones anteriores los componentes a utilizar y su interacción con el sistema, es momento de calcular las dimensiones de la máquina para analizar la flotabilidad y seleccionar flotadores adecuados. En las siguientes subsecciones se analizan los cálculos, selección y diseño del sistema de flotación.% En la Figura \ref{fig:subsistema de flotacion} se enumera los componentes principales: 

\begin{myfigure}[H]
	\footnotesize\centering
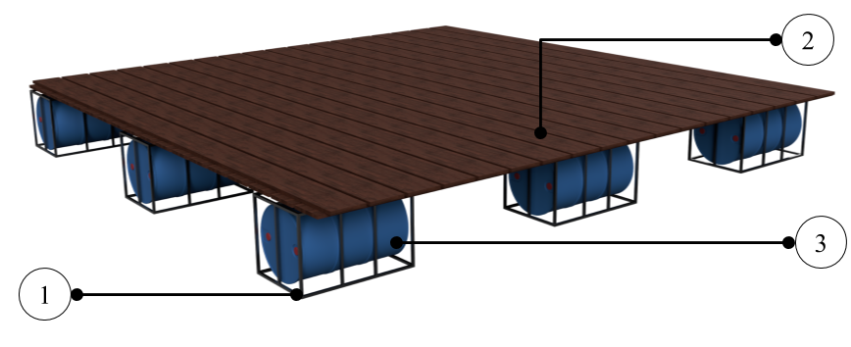
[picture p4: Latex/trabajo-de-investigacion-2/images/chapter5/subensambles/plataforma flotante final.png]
	
	\caption{Subsistema de flotación}
	\begin{myflushcenter}
		Leyenda: (1) armadura de cilindro de flotación; (2) superficie de madera y marco de metal interior; (3) cilindro de flotación.\\
		Fuente: Elaboración propia.
	\end{myflushcenter}
	\label{fig:subsistema de flotacion}
\end{myfigure}

\vspace{-2.0em}

%% NUEVO SECCION X.X.X.
\subsection{Sistema para mantener a flote el sistema}

La plataforma flotante de 5x5 m. que se muestra en la Figura \ref{fig:subsistema de flotacion} es empleada por las empresas en el sector de crianza de truchas en lagunas por su flotabilidad y área útil que brinda a los operarios. En el caso de la CCT, ocupa un área pequeña de 2.5x1m pero con un peso aproximado de 260 kg. Por lo que, como se muestra en la Figura \ref{fig:refuerzo subsistema de flotacion}, se agregan refuerzos para evitar que la CCT se desplace libremente.

\begin{myfigure}[H]
	\footnotesize\centering
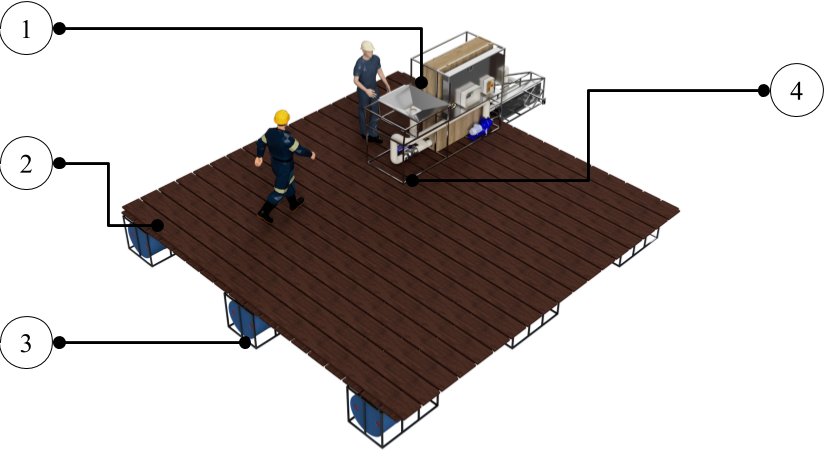
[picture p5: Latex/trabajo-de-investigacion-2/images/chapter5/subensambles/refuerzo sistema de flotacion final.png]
	
	\caption{Fuerzas necesarias para mantener a flote el sistema}
	\begin{myflushcenter}
		Fuente: Elaboración propia.
	\end{myflushcenter}
	\label{fig:refuerzo subsistema de flotacion}
\end{myfigure}

En la Figura \ref{fig:refuerzo subsistema de flotacion} se enumeran los principales elementos: 1. Máquina CCT; 2. Plataforma de madera con refuerzo de marco de acero interior; 3. cilindros con armazón que sirven de flotación; 4. Lugares de refuerzo para fijación a la plataforma de madera. Cabe resaltar que en el presente trabajo no se considera el sistema de flotación dentro del presupuesto, sino que sirve de manera expositiva sobre cómo es que funciona y de qué materiales usualmente está hecho, esto se expone debido a que la problemática se desarrolla en la Laguna de Paucarcocha y usualmente las empresas de producción acuícola poseen este tipo de plataformas que les sirve para otros procesos como los de repartir comida o realizar procesos manuales.

%----------------------------------------------------------------------------------------
%	Capítulo 5 
%----------------------------------------------------------------------------------------

\pagestyle{myportland}
%\pagenumbering{arabic}
\doublespacing
\chapter[\quad\quad\quad\quad ----- Diseño de subsistema de recepción, distribución y traslado de truchas]{\\ Diseño de subsistema de recepción, distribución y traslado de truchas}
\thispagestyle{myportland}

\label{ssec:diseno de subsistema de recepcion, distribucion y traslado de truchas}

Este subsistema consiste en encapsular los mecanismos físicos que están en el ciclo que sigue una trucha dentro de la máquina: tolva, tuberías, bomba de agua, distribución física por mecanismos, caudales apropiados y el control respectivo. Los puntos mencionados se detallan en las siguientes páginas. % En la Figura \ref{fig:subsistema de recepción, distribución y traslado de truchas} se muestran los tres sistemas: 

\begin{myfigure}[H]
	\footnotesize\centering
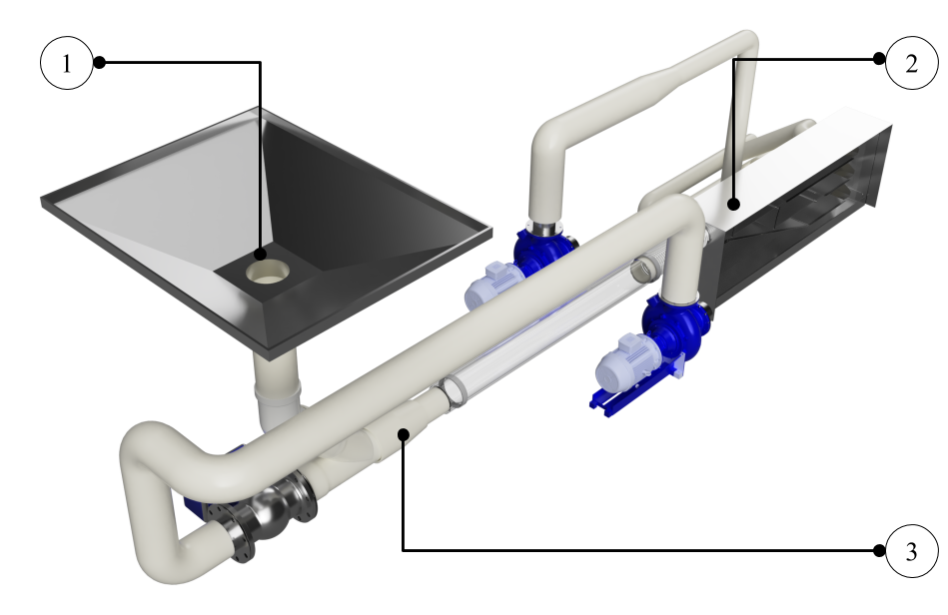
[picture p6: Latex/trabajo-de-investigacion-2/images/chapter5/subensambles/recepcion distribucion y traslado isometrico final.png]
	
	\caption{Subsistema de recepción, distribución y traslado de truchas}
	\begin{myflushcenter}
		Leyenda: Subsistemas de (1) recepción; (2) distribución; (3) distribución.\\
		Fuente: Elaboración propia.
	\end{myflushcenter}
	\label{fig:subsistema de recepción, distribución y traslado de truchas}
\end{myfigure}

\vspace{-2.0em}

%% NUEVO SECCION X.X.
\section{Diseño del subsistema de recepción de truchas}

El subsistema de recepción de truchas se encarga de únicamente a recopilar las truchas mediante una tolva como se muestra en la Figura \ref{fig:subsistema de recepcion}.

\begin{myfigure}[H]
	\footnotesize\centering
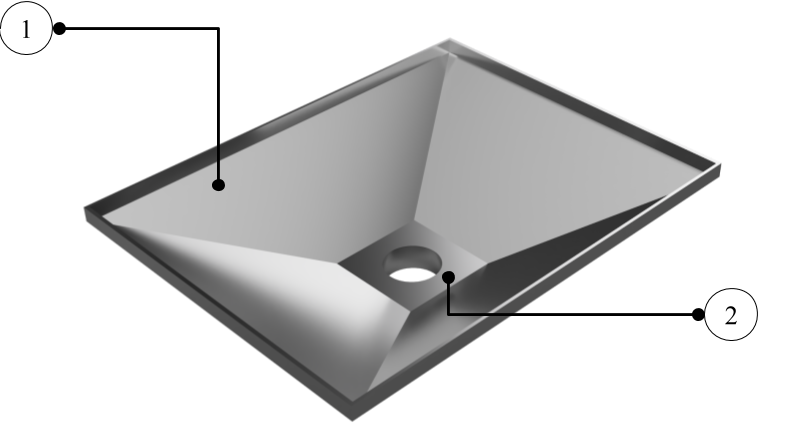
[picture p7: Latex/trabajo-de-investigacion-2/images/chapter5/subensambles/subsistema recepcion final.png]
	
	\caption{Mecanismo de distribución de truchas}
	\begin{myflushcenter}
		Leyenda: (1) borde de tolva; (2) base de tolva. \\
		Fuente: Elaboración propia.
	\end{myflushcenter}
	\label{fig:subsistema de recepcion}
\end{myfigure}
\vspace{-2.0em}

%% NUEVO SECCION X.X.X
\subsection{Cálculos dimensiones del subsistema de recepción de truchas}

El diseño implica un análisis sobre las situaciones que suceden cuando se realiza el proceso de depositar las truchas. En la Figura \ref{fig:calculo de dimensiones y angulo de la tolva} se analiza dicha situación con la finalidad de escoger un ángulo de elevación de la tolva ($\beta$) adecuado. Respecto a la tolva, se designan los siguientes valores iniciales: $A_{min},B_{min}=200 mm.$; $\beta \in [0;45] ^\circ$; ${tolva}=150 mm.$. Además, debe cumplirse que $A_{max}>B_{max}$ orientado hacia el operario que depositará la trucha.

\begin{myfigure}[H]
	\footnotesize\centering
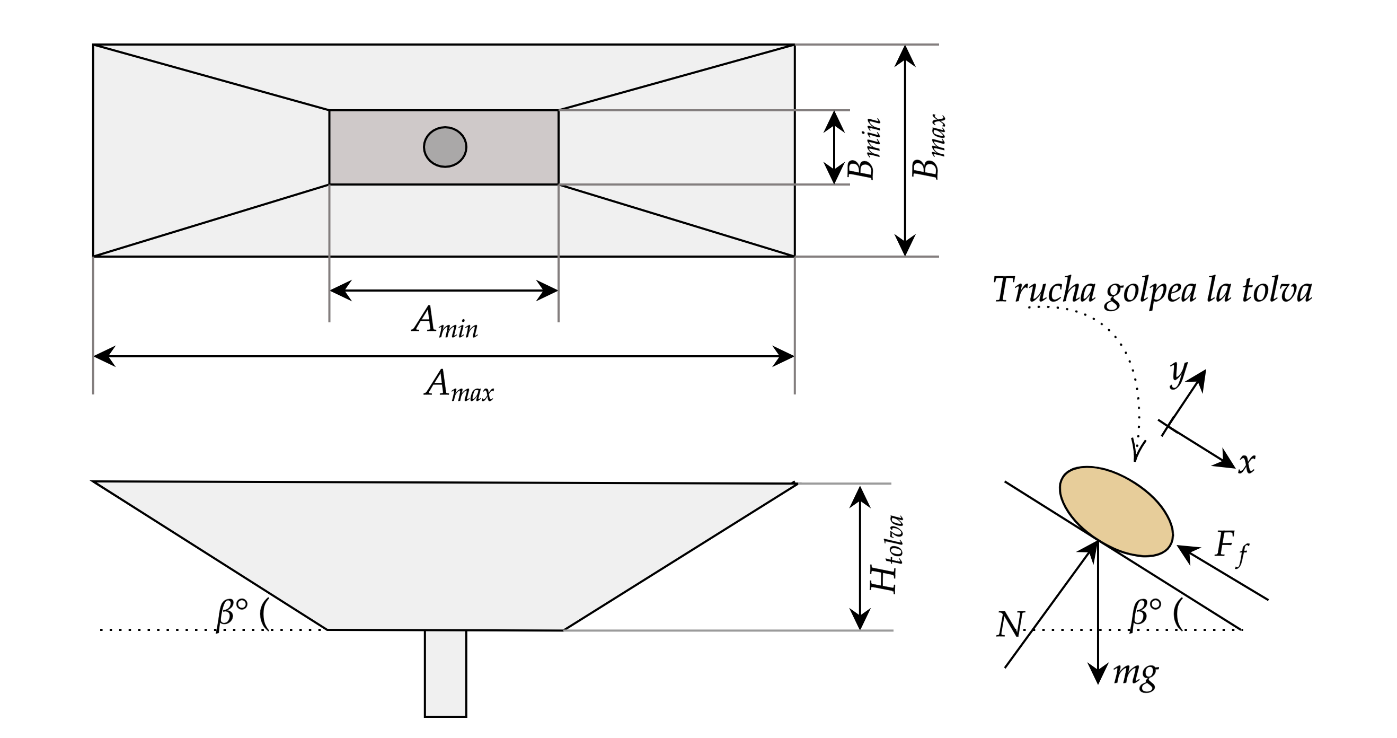
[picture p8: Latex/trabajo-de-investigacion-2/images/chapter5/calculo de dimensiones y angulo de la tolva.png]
	
	\caption{Cálculo de dimensiones y ángulo de la tolva}
	\begin{myflushcenter}
		Fuente: Elaboración propia.
	\end{myflushcenter}
	\label{fig:calculo de dimensiones y angulo de la tolva}
\end{myfigure}

Parte de la Figura \ref{fig:calculo de dimensiones y angulo de la tolva} muestra el diagrama de cuerpo libre del cual se extrae la fuerza de fricción ($F_{f}$) y la fuerza normal ($N$) que se muestran en la Ecuación \ref{eq:calculo de angulo de la tolva}. Las leyes de Newton se muestran en la Ecuación \ref{eq:leyes de newton}. 

\begin{myequation}\label{eq:leyes de newton}
	\begin{split}
		F_{R}=m*a \\
		\sum_{0}^{n}F_{x,y,z}=0
	\end{split}
\end{myequation}

\begin{myequation}\label{eq:calculo de angulo de la tolva}
	\begin{split}
		F_{f}=\mu*N  \\
		\sum_{}^{}F_{y}=N-mg*cos(\beta)=0
	\end{split}
\end{myequation}

Luego, se reemplazan la Ecuación \ref{eq:calculo de angulo de la tolva} en la Ecuación \ref{eq:leyes de newton} y se obtiene la Ecuación \ref{eq:calculo de angulo de la tolva2}. La variable a despejar es la aceleración en el eje x ($\ddot{x}$).

\begin{myequation}\label{eq:calculo de angulo de la tolva2}
	\begin{split}
		mg*sin(\beta)-F_{f}&=m*\ddot{x} \\
		mg*sin(\beta)-\mu_{k}*mg*cos(\beta)&=m*\ddot{x} \\
		g*sin(\beta)-g*\mu_{k}*cos(\beta)&=\ddot{x}
	\end{split}
\end{myequation}

Para disminuir el impacto de la trucha sobre la tolva o sobre las tuberías interiores se debe disminuir la aceleración de la trucha al ser depositada en la tolva. La Figura \ref{fig:grafico angulo de tolva vs aceleracion} muestra la ecuación que relaciona la aceleración con el ángulo de elevación de la pared de la tolva. Consecuentemente, se escoge un ángulo ($\beta=30^\circ$) para tener una aceleración aproximadamente nula ($\ddot{x}\approx0$). Se considera $\mu_{k}=0.57$ para el material escogido en la sección \ref{sssec:seleccion de materiales de fabricacion}. Consecuentemente, se calculan los valores de $A_{max}\approx{900} mm.$ y $B_{max}\approx{700} mm.$, respectivamente.

% Material escogido Acero inoxidable

\begin{myfigure}[H]
	\footnotesize\centering
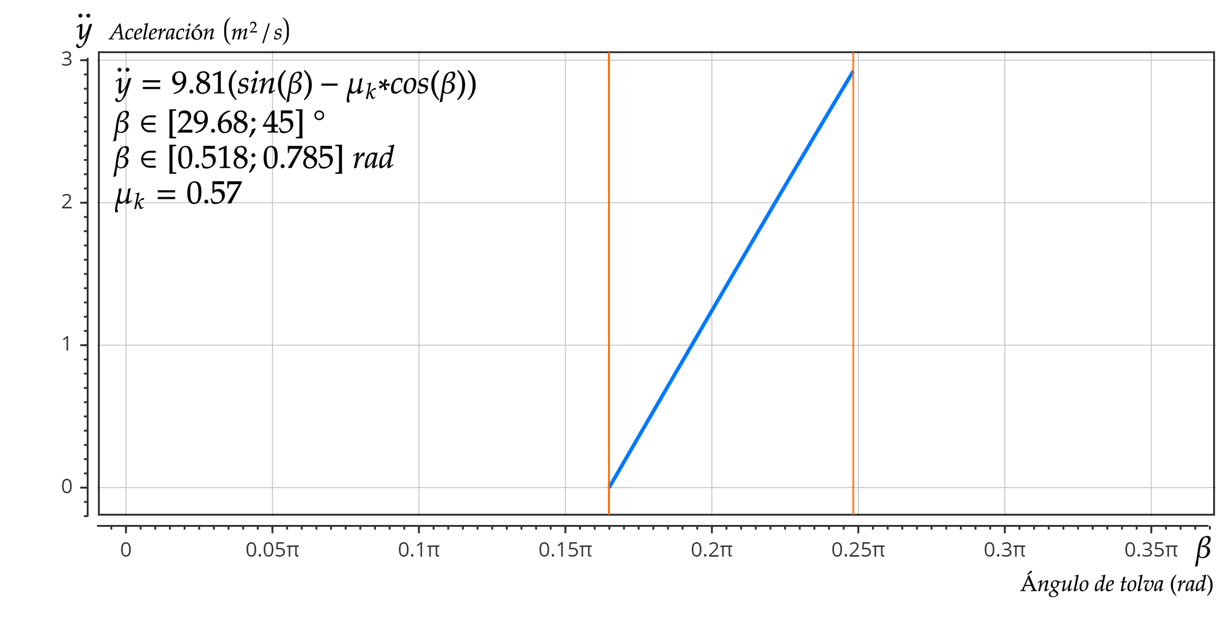
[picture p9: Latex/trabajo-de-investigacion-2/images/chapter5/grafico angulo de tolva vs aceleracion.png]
	
	\caption{Ángulo de tolva vs aceleración en la trucha}
	\begin{myflushcenter}
		Fuente: Elaboración propia.
	\end{myflushcenter}
	\label{fig:grafico angulo de tolva vs aceleracion}
\end{myfigure}

\vspace{-2.0em}

%% NUEVO SECCION X.X.
\section{Diseño de subsistema de distribución de truchas}

Luego del proceso de procesamiento de imágenes el sistema mediante el algoritmo de clasificación indica al sistema la trayectoria que debe seguir la trucha en tránsito y es accionado por el mecanismo de distribución, mostrado en las Figuras \ref{fig:mecanismo de distribucion de truchas} y \ref{fig:mecanismo de distribucion de truchas2}. Dicho mecanismo recibe a la trucha por una única entrada y redirige mediante un juego de compuertas a tres salidas. Finalmente, las truchas son impulsadas al ingresar a tuberías con caudal de agua constante que las transporta hasta las jaulas flotantes correspondientes.

\begin{myfigure}[H]
	\footnotesize\centering
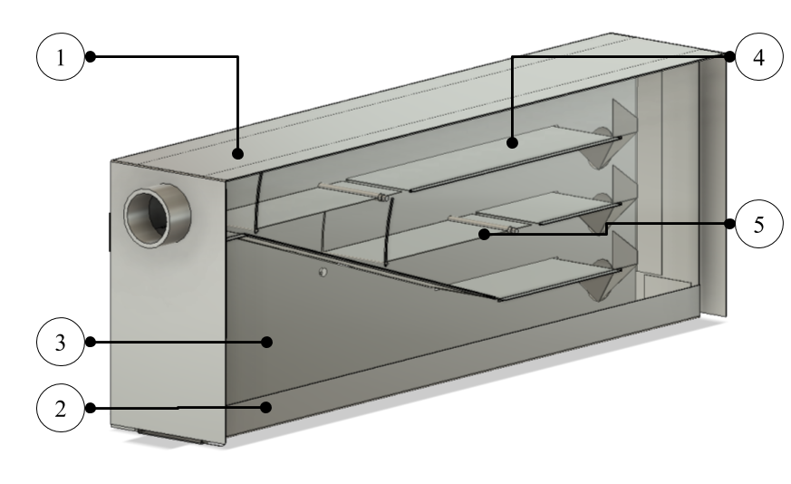
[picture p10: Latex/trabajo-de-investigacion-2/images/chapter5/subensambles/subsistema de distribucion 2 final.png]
	
	\caption{Mecanismo de distribución de truchas - Vista isométrica}
	\begin{myflushcenter}
		Leyenda: (1) placa tipo tapa; (2) pared a de la distribuidora; (3) pared b de la distribuidora; (4) placa intermedia; (5) mecanismo de compuerta\footnote{La leva no se muestra adecuadamente en esta vista.} \\
		Fuente: Elaboración propia.
	\end{myflushcenter}
	\label{fig:mecanismo de distribucion de truchas}
\end{myfigure}

\begin{myfigure}[H]
	\footnotesize\centering
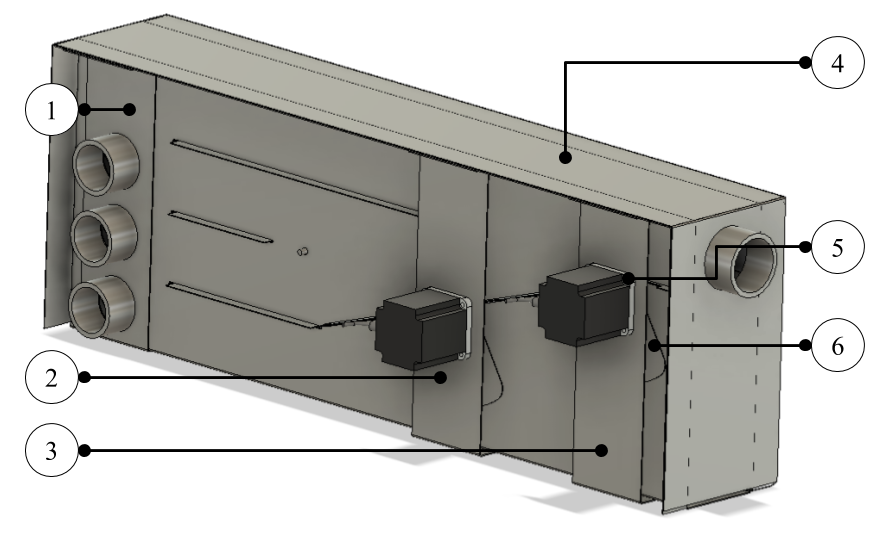
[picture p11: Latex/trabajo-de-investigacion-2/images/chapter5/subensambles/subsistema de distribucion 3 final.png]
	
	\caption{Mecanismo de distribución de truchas - Vista isométrica opuesta}
	\begin{myflushcenter}
		Leyenda: (1) lengüeta de salida; (2) lengüeta de servomotor 2; (3) lengüeta de servomotor 1; (4) placa tipo tapa; (5) servomotor; (6) leva.\\
		Fuente: Elaboración propia.
	\end{myflushcenter}
	\label{fig:mecanismo de distribucion de truchas2}
\end{myfigure}

\vspace{-2.0em}

%% NUEVO SECCION X.X.X.
\subsection{Selección de mecanismo que acciona la compuerta}
	
La selección del mecanismo que activa la compuerta tiene requisitos técnicos que son muy importantes, de no funcionar puede parar completamente el proceso general, por lo que se realiza una comparación de los posibles mecanismos a utilizar para hacer girar la compuerta de manera cíclica ordenado por el subsistema de control. La comparación conceptual se muestra en la Tabla \ref{tab:tabla comparativa de conceptos de mecanismos para compuerta} y los conceptos de mecanismos analizados se muestran en la Figura \ref{fig:conceptos de mecanismos de distribucion de truchas}.
	
\begin{myfigure}[H]
	\footnotesize\centering
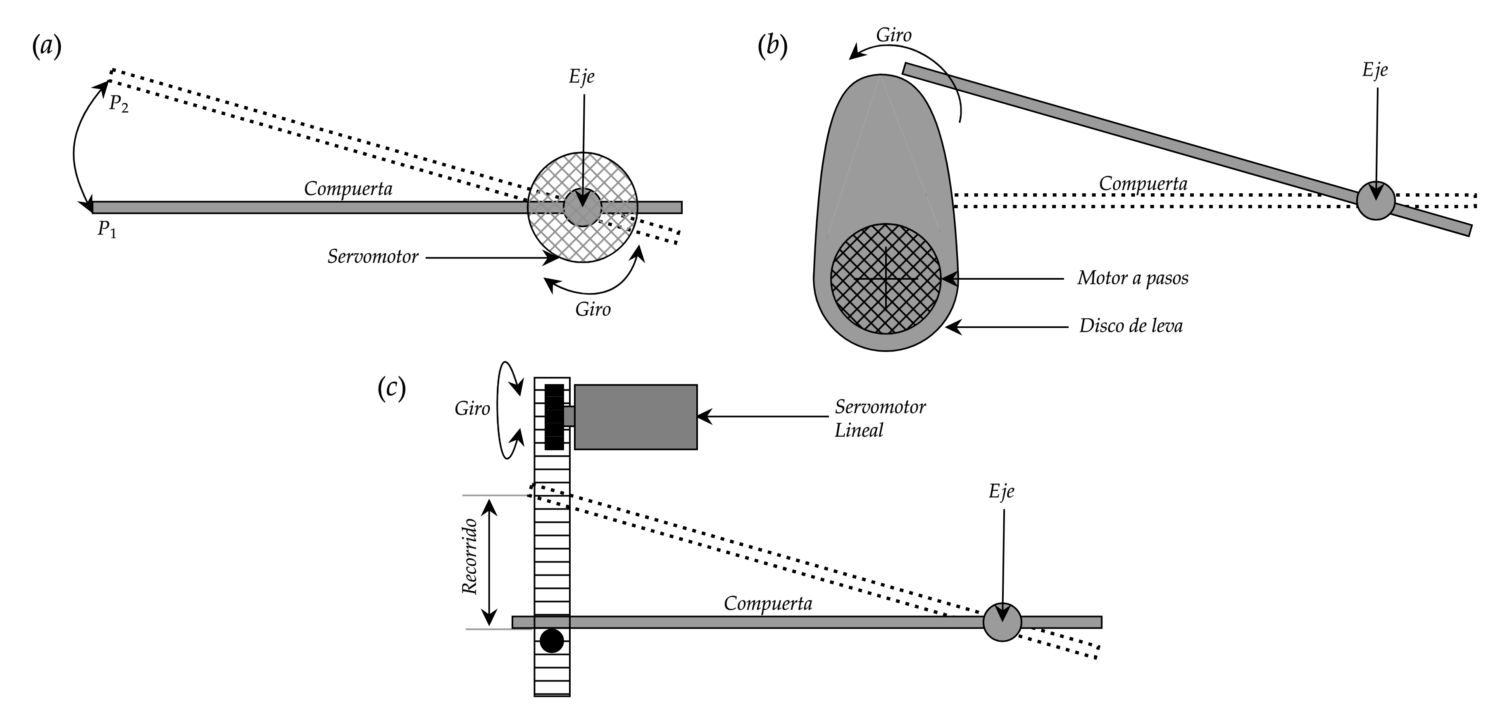
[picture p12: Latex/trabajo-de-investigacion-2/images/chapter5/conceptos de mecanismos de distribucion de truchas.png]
	
	\caption[Conceptos de mecanismos de distribución de truchas]{(a) Mecanismo de eje servomotor. (b) Mecanismo de tolva y seguidor. (c) Mecanismo de servomotor lineal.}
	\begin{myflushcenter}
		Fuente: Elaboración propia.
	\end{myflushcenter}
	\label{fig:conceptos de mecanismos de distribucion de truchas}
\end{myfigure}
	
El mecanismo inicialmente propuesto (Figura \ref{fig:conceptos de mecanismos de distribucion de truchas}-a) corresponde a un servomotor conectado al eje de la compuerta del sistema de distribución, los apoyos no son representados en las figuras. El sistema, al efectuar cierta cantidad de giros en un periodo largo\footnote{Una jornada diaria de clasificación puede someter al mecanismo a abrir/cerrar la compuerta en $t_{compuerta}\approx1 s.$ durante $t_{jornadaxdia}=6 h.$} presenta un deterioro considerable en el eje del servomotor, por lo que se analiza un mecanismo de leva-seguidor (Figura \ref{fig:conceptos de mecanismos de distribucion de truchas}-b) que traslada el giro fuera del eje, en un solo sentido y se aplica el giro sobre un extremo de la compuerta, el disco de leva está posicionado para brindar un movimiento armónico al extremo de la compuerta. Así también, se considera un mecanismo de servomotor lineal que mediante una traba en la cremallera desplaza la compuerta hasta la posición requerida mediante giros en los dos sentidos.

\begin{savenotes}	
	\begin{mytable}[H]
		\footnotesize\centering
		\caption{Tabla comparativa de conceptos de mecanismos.}
		\label{tab:tabla comparativa de conceptos de mecanismos para compuerta}
		\begin{tabular}{l|c|c|c|c|}
			\cline{2-5}
			\multicolumn{1}{c|}{\textbf{}} & 
			\textbf{\begin{tabular}[c]{@{}c@{}}Requisitos\\ mínimos\end{tabular}} & \begin{minipage}{\mythirdmaxsizeofcontenttable}\begin{myflushcenterinsidetable}
					\textbf{Servomotor de rotación posicional}
			\end{myflushcenterinsidetable}\end{minipage} & 
			\begin{minipage}{\mythirdmaxsizeofcontenttable}\begin{myflushcenterinsidetable}
					\textbf{Leva y seguidor}
			\end{myflushcenterinsidetable}\end{minipage} &
			\begin{minipage}{\mythirdmaxsizeofcontenttable}\begin{myflushcenterinsidetable}
					\textbf{Servomotor lineal}
			\end{myflushcenterinsidetable}\end{minipage} \\ \hline
			%\multicolumn{1}{|l|}{\textbf{Figura}} & - & 
			%Figura \ref{fig:conceptos de mecanismos de distribucion de truchas}-a &
			%Figura \ref{fig:conceptos de mecanismos de distribucion de truchas}-b &
			%Figura \ref{fig:conceptos de mecanismos de distribucion de truchas}-c \\ \hline
			\multicolumn{1}{|l|}{
				\begin{minipage}{\myforthmaxsizeofcontenttable}			
					\textbf{Cantidad de sentidos de giro}
				\end{minipage}
			} & 1 & 2 & 1 & 2 \\ \hline
			\multicolumn{1}{|l|}{
				\begin{minipage}{\myforthmaxsizeofcontenttable}			
					\textbf{Complejidad mecánica\footnote{Basado en cantidad de componentes actuadores.}}
				\end{minipage}
			} & 1 & 1 & 2 & 2 \\ \hline
			\multicolumn{1}{|l|}{
				\begin{minipage}{\myforthmaxsizeofcontenttable}			
					\textbf{Disponibilidad en el mercado\footnote{Basado en el componente más "difícil" de conseguir.Calificación cualitativa: nacional o internacional}}
				\end{minipage}
			} & - & Nacional & Internacional & Nacional \\ \hline
			\multicolumn{1}{|l|}{
				\begin{minipage}{\myforthmaxsizeofcontenttable}			
					\textbf{Torque máximo\footnote{Basado en situación crítica encontrada derivando la ecuación de torque respectivo. Dónde: $d_{eje}$ es la distancia del centro de gravedad de la compuerta al eje, $d_{leva}$ es la distancia del centro del disco de leva hasta la parte más alejada de este y $d_{ser}$ es diámetro del engranaje en el mecanismo piñón-cremallera del servomotor lineal. ($d_{ser}<d_{leva}<d_{eje}$)} ($\overrightarrow{\tau_{max}}$)}	
				\end{minipage}
			} & - & $\approx m*g*d_{eje}$ & $\approx m*g*d_{leva}/2$ & $\approx m*g*d_{ser}/4$ \\ \hline
			%\multicolumn{1}{|l|}{
			%	\begin{minipage}{\myforthmaxsizeofcontenttable}			
			%		\textbf{Desgaste\footnote{Calificación cualitativa: bajo, medio o alto.}}
			%	\end{minipage}
			%} & - & Alto & Bajo & Medio \\ \hline
			\multicolumn{1}{|l|}{
				\begin{minipage}{\myforthmaxsizeofcontenttable}			
					\textbf{Acoplamiento al sistema\footnote{Basado en cantidad de componentes adicionales necesarios para implementar. }}
				\end{minipage}
			} & 1 & 1 & 2 & 3 \\ \hline
			\multicolumn{1}{|l|}{
				\begin{minipage}{\myforthmaxsizeofcontenttable}			
					\textbf{Actuador que genera ruido\footnote{Componente que genera sonido.}}
				\end{minipage}
			} & - & Servomotor rotatorio & Motor a pasos & Servomotor lineal \\ \hline
		\end{tabular}
		\begin{myflushcenteraftertable}	
			Fuente: Elaboración propia.
		\end{myflushcenteraftertable}
	\end{mytable}
\end{savenotes}	

El mecanismo escogido es el leva y seguidor ya que solo es necesario su giro en un sentido, lo cual disminuye el desgaste, se acopla al sistema sin implementar más soportes que los otros mecanismos, no genera ruido y su fabricación, en caso no se encuentre en el mercado peruano, se puede realizar en un taller nacional.  	

%% NUEVO SECCION X.X.X.
\subsection{Diseño de mecanismo que acciona la compuerta}
	
En cuanto al mecanismo determinado, se realiza una análisis simple para determinar la forma que tendrá el disco de leva (\ref{fig:mecanismo compuerta}-b) y con ese fin se realiza un diagrama de cuerpo libre (\ref{fig:mecanismo compuerta}-a) que permite analizar las fuerzas sobre los cuerpos.

\begin{myfigure}[H]
	\footnotesize\centering
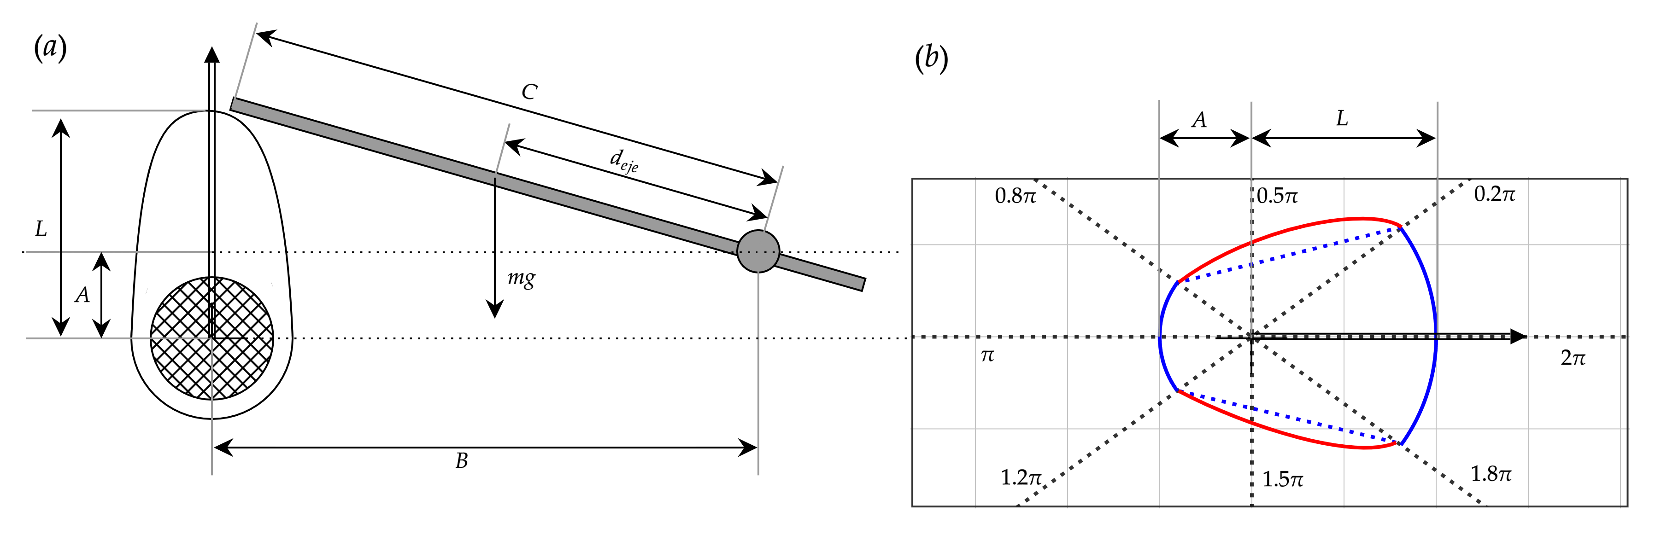
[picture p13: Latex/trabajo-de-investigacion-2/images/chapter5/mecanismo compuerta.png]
	
	\caption[Mecanismo leva-seguidor]{(a) Diagrama de cuerpo libre de mecanismo leva-seguidor. (b) Dimensiones del disco de leva.}
	\begin{myflushcenter}
		Fuente: Elaboración propia.
	\end{myflushcenter}
	\label{fig:mecanismo compuerta}
\end{myfigure}

El diseño del disco de leva que se muestra en la Figura \ref{fig:mecanismo compuerta}-b corresponde al posicionamiento requerido (línea azul) y a un posicionamiento óptimo (línea roja). Dicho posicionamiento versus el ángulo de giro se muestra en la Figura \ref{fig:mecanismo compuerta leva posicionamiento}. 

\begin{myfigure}[H]
	\footnotesize\centering
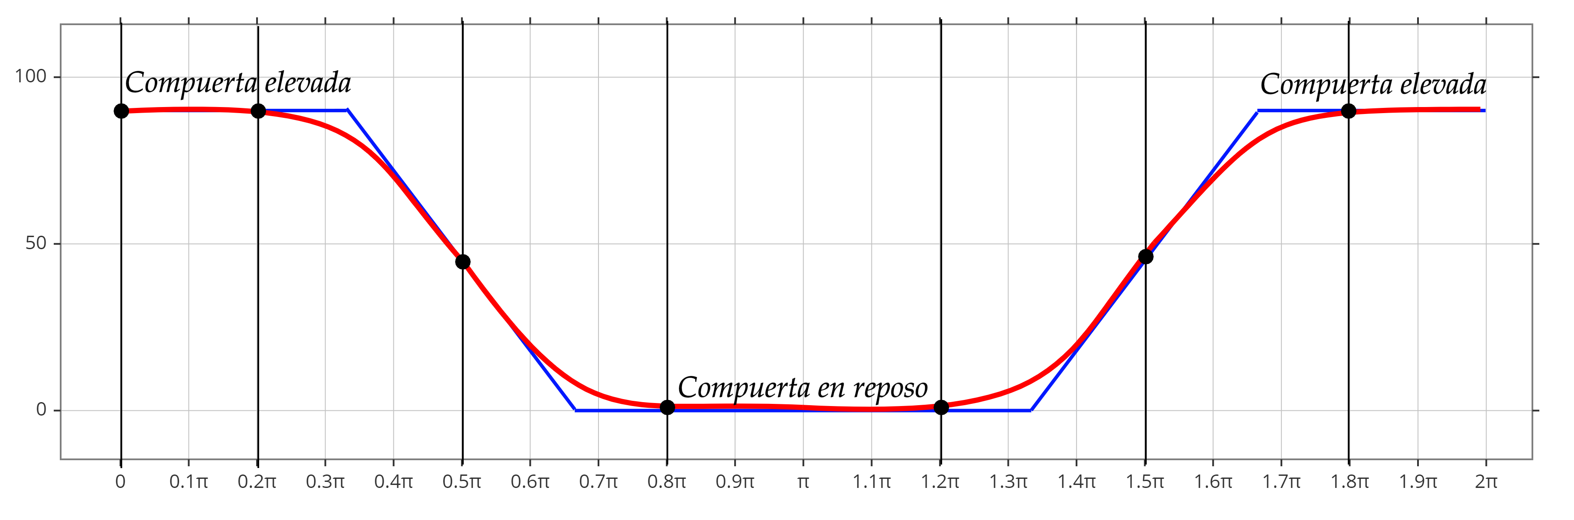
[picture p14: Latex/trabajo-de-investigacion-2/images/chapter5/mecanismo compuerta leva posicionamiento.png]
	
	\caption{Engranajes del mecanismo de compuertas}
	\begin{myflushcenter}
		Fuente: Elaboración propia.
	\end{myflushcenter}
	\label{fig:mecanismo compuerta leva posicionamiento}
\end{myfigure}

%% NUEVO SECCION X.X.X.
\subsection{Cálculo de torque sobre la compuerta}

El torque necesario para abrir y cerrar la compuerta se aplica sobre el eje de la mima. La parte más alejada del disco de leva es la que levanta la compuerta. En la Figura \ref{fig:dlc leva compuerta}, la fuerza $N$ representa la normal que se aplica debido al peso de la compuerta cuando se abre en giro horario. Además, donde: [$R_x$, $R_y$] son reacciones en un determinado punto, en este caso sobre el eje del disco de leva y de la compuerta, respectivamente; [$C$, $d_{eje}$, $L$ y $A$] son distancias; y [$mg$ y $N$] son fuerzas a la que están sometidas las cuerpos.

\begin{myfigure}[H]
	\footnotesize\centering
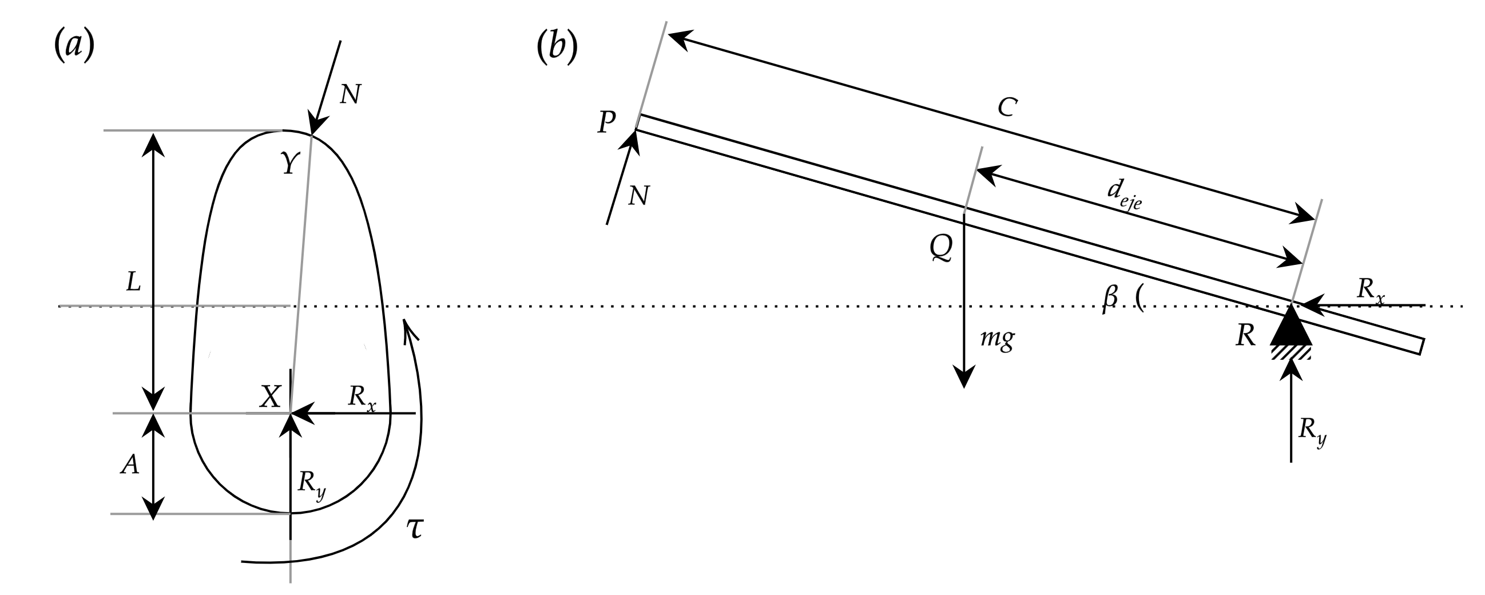
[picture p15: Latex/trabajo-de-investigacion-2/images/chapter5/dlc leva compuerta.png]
	
	\caption[Diagrama de cuerpo libre del mecanismo de la compuerta]{(a) DLC del disco de leva. (b) DLC de la compuerta.}
	\begin{myflushcenter}
		Fuente: Elaboración propia.
	\end{myflushcenter}
	\label{fig:dlc leva compuerta}
\end{myfigure}

Para hallar el valor de la fuerza $N$, en el DLC de la compuerta (Figura \ref{fig:dlc leva compuerta}-b) se suma los momentos en el punto $R$ como se expone en la Ecuación \ref{eq:calculo fuerza normal}.	

\begin{myequation}\label{eq:calculo fuerza normal}
	\begin{split}
		\sum_{}^{}M_{R}&=m_{compuerta}*g*cos(\beta)*d_{eje}-2*N*d_{eje}=0 \\
		N&=\frac{m_{compuerta}*g*cos(\beta)}{2}			
	\end{split}		
\end{myequation}

Luego, analizamos realizamos la sumatoria de momentos en el punto $X$ en el DLC del disco de leva que se muestra en la Figura \ref{fig:diagrama de cuerpo libre del mecanismo de la leva}. 

\begin{myfigure}[H]
	\footnotesize\centering
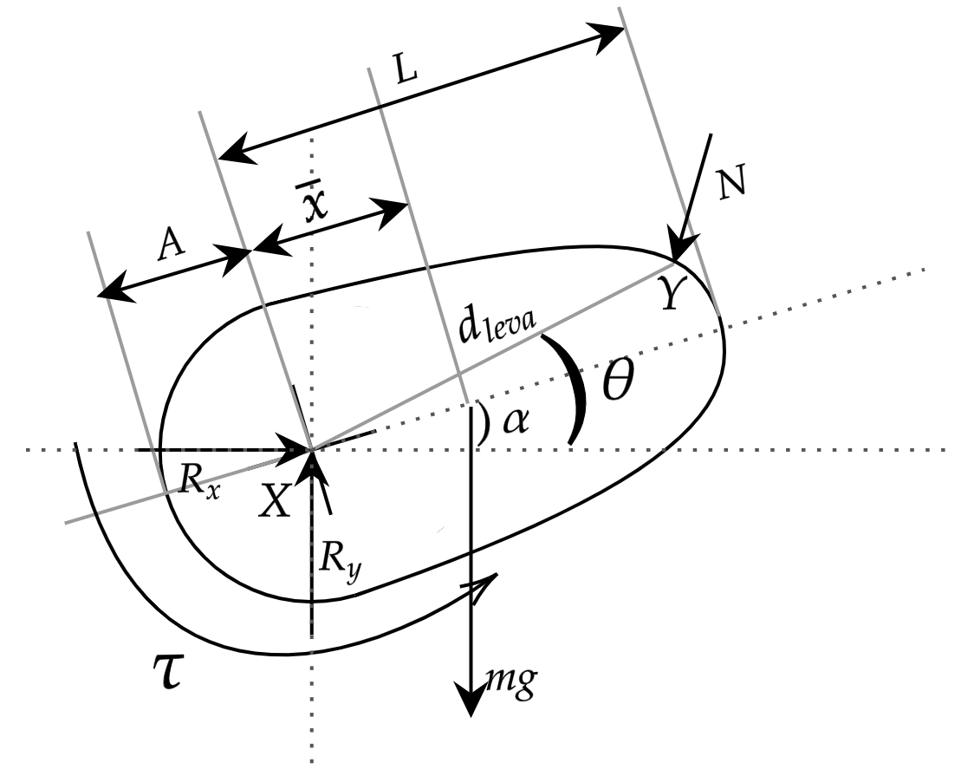
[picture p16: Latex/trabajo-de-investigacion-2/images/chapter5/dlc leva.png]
	
	\caption{Diagrama de cuerpo libre del mecanismo de la leva}
	\begin{myflushcenter}
		Fuente: Elaboración propia.
	\end{myflushcenter}
	\label{fig:diagrama de cuerpo libre del mecanismo de la leva}
\end{myfigure}

Luego, se reemplaza el valor de $N$ en la sumatoria de momentos en el punto $X$, del DLC del disco de leva, y se obtiene el torque máximo ($\overrightarrow{\tau_{max}}$) como se muestra en la Ecuación \ref{eq:calculo de torque máximo}.

\begin{myequation}\label{eq:calculo de torque máximo}
	\begin{split}
		\sum_{}^{}M_{X}&=-m_{leva}*g*\bar{x}*cos(\alpha)+\tau-N*d_{leva}*(cos(\beta)cos(\theta)-sin(\beta)sin(\theta))=0 \\
		\tau_{max}&=m_{leva}*g*\bar{x}+N*d_{leva} \\
	\end{split}		
\end{myequation}

Dónde: $\bar{x}$ es el centro de gravedad, asumiendo material uniforme, $d_{leva}$ es la distancia del punto de apoyo $X$ al punto de contacto con la compuerta $Y$, $\theta$ es el ángulo que forma el punto de contacto respecto al eje $x$, $\alpha$ es el ángulo que se forma del eje $x$ al eje de simetría de la leva. Conocer el torque máximo ($\tau_{max}$) delimita la selección de un motor a pasos a base del par de fuerza máximo generado.

\begin{myequation}\label{eq:calculo de centro de gravedad}
	\begin{split}
		\bar{x}&=(\frac{2*sin(0.2*\pi)*(L-A)}{\pi}+2*\frac{L*cos(0.2*\pi)-A*cos(\pi)}{3})/4 \\
		\bar{x}&=54.23 \\	
	\end{split}		
\end{myequation}

\begin{myequation}\label{eq:calculo de masa de leva}
	\begin{split}
		m_{leva}&=V_{L}*\rho_{L}=39111.24*7.8/1000 \quad\quad (AISI 306 - e_{L}=3mm) \\
		m_{leva}&=305.06g=0.305kg \\		
	\end{split}		
\end{myequation}

\begin{myequation}\label{eq:calculo de masa de compuerta}
	\begin{split}
		m_{compuerta}&=V_{c}*\rho_{c}=41400*7.8/1000 \quad\quad (AISI 306 - e_{L}=1mm) \\
		m_{compuerta}&=322.92g=0.323kg \\	
	\end{split}		
\end{myequation}

\begin{myequation}\label{eq:calculo de fuerza normal maxima}
	\begin{split}
		N_{max}&=\frac{m_{c}*g}{2} \quad\quad (\beta=0^{\circ}) \\
		N_{max}&=\frac{0.323*9.8}{2}=1.579 \\		
	\end{split}		
\end{myequation}

Reemplazando los valores de las Ecuaciones \ref{eq:calculo de centro de gravedad}, \ref{eq:calculo de masa de leva}, \ref{eq:calculo de masa de compuerta} y \ref{eq:calculo de fuerza normal maxima} en la Ecuación \ref{eq:calculo de torque máximo} se obtiene el valor del torque máximo que es el mismo valor del par mínimo de fuerzas necesarias para seleccionar el motor a pasos. En la Ecuación \ref{eq:calculo de torque maximo 2} se calcula el valor del par de fuerzas.

\begin{myequation}\label{eq:calculo de torque maximo 2}
	\begin{split}
		\tau_{max}&=0.305*9.81*0.054+0.12*0.322*9.81/2 \\
		\tau_{max}&=1.86 \quad Nm \\
	\end{split}		
\end{myequation}

%	\begin{myequation}\label{eq:calculo de torque máximo}
%		\begin{split}
%			\overrightarrow{\tau_{X}}&=N*sin(\beta)*L \\
%			\overrightarrow{\tau_{X}}&=\frac{m*g*cos(\beta)}{2}*sin(\beta)*L \\
%			\overrightarrow{\tau_{X}}&=m*g*L*\frac{sin(2\beta)}{2} \\
%			\overrightarrow{\tau_{X_{max}}}&=\frac{m*g*L}{2} \quad (\beta=45^\circ) \\
%		\end{split}		
%	\end{myequation}

%	\item \textbf{Cálculo de velocidad de giro de la compuerta}

%	\textcolor{blue}{[BORRADOR] Falta pasar a limpio los cálculos [/BORRADOR]}

%	\begin{myfigure}[H]
%		\footnotesize\centering
%		\includegraphics[width=1\textwidth]{chapter5/torque necesario.png}
%		\caption{Curva de torque necesario}
%		\begin{myflushcenter}
%			Fuente: Elaboración propia.
%		\end{myflushcenter}
%		\label{fig:curva de torque necesario}
%	\end{myfigure}

%	\textcolor{blue}{[BORRADOR] La velocidad de compuertas debe ir acorde a la distancia entre una trucha y la siguiente a esta.  Explicar velocidad RPM necesarias y explicar las ecuaciones siguientes [/BORRADOR]}

%	\begin{myequation}\label{eq:calculo de rpms}
%		\begin{split}
%			RPM_{necesarias}&=1 \\
%		\end{split}		
%	\end{myequation}

%% NUEVO SECCION X.X.X.
\subsection{Selección de motores a paso}
	
La selección de los motores a pasos depende se da acorde a los cálculos en las subsecciones anteriores, existe una gran variedad en cuanto a este tipo de dispositivos en el mercado internacional.En la Tabla \ref{tab:tabla comparativa de motores a pasos} se muestra una comparación técnica entre tres motores a pasos que cumplen los requisitos mínimos.	 

\begin{mytable}[H]
	\footnotesize\centering
	\caption{Tabla comparativa de motores a pasos.}
	\label{tab:tabla comparativa de motores a pasos}
	\begin{tabular}{l|c|c|c|c|}
		\cline{2-5}
		\multicolumn{1}{c|}{\textbf{}} & \textbf{\begin{tabular}[c]{@{}c@{}}Requisitos\\ mínimos\end{tabular}} &
		\begin{minipage}{\mythirdmaxsizeofcontenttable}\begin{myflushcenterinsidetable}
			\textbf{57J1880-450}
		\end{myflushcenterinsidetable}\end{minipage} &		
		\begin{minipage}{\mythirdmaxsizeofcontenttable}\begin{myflushcenterinsidetable}
			\textbf{Nema 34}
		\end{myflushcenterinsidetable}\end{minipage} &	
		\begin{minipage}{\mythirdmaxsizeofcontenttable}\begin{myflushcenterinsidetable}
			\textbf{ZL57HS09}
		\end{myflushcenterinsidetable}\end{minipage} \\ \hline
		\multicolumn{1}{|l|}{\textbf{Figura}}     & -                                                                     
		&
		\begin{minipage}{\mythirdmaxsizeofcontenttable}
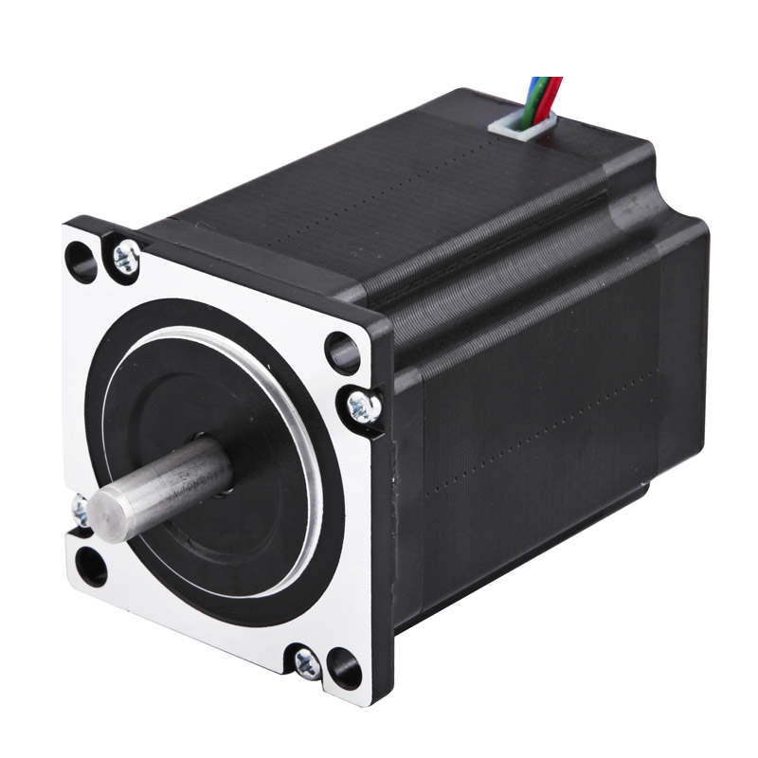
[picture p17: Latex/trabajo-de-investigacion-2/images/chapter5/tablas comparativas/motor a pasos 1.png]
			\centering \\ 
			%\begin{myflushcenter}
			%	{\footnotesize Nombre imagen}
			%\end{myflushcenter}
		\end{minipage} 
		&
		\begin{minipage}{\mythirdmaxsizeofcontenttable}
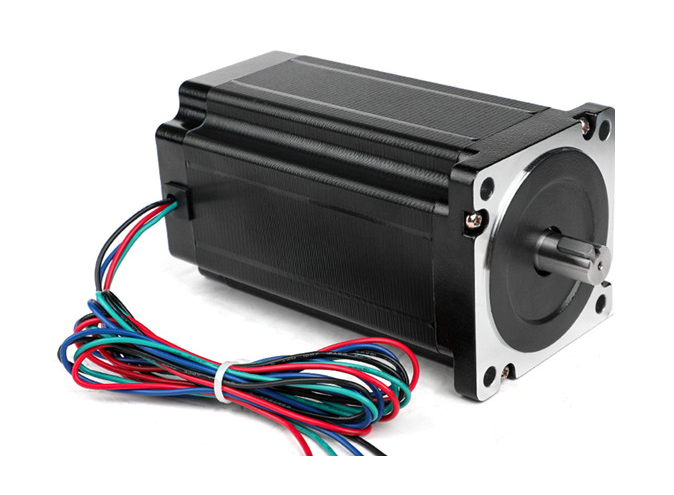
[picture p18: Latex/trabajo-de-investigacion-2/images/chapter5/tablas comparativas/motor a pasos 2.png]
			\centering \\ 
			%\begin{myflushcenter}
			%	{\footnotesize Nombre imagen}
			%\end{myflushcenter}
		\end{minipage} 
		&
		\begin{minipage}{\mythirdmaxsizeofcontenttable}
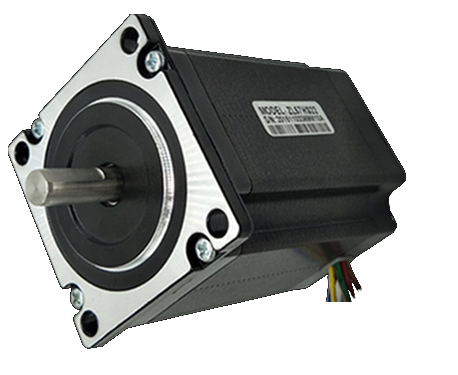
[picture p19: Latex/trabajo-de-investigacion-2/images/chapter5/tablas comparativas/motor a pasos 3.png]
			\centering \\ 
			%\begin{myflushcenter}
			%	{\footnotesize Nombre imagen}
			%\end{myflushcenter}
		\end{minipage} 
		\\ \hline
		\multicolumn{1}{|l|}{\textbf{Fabricante}} & - &
		\begin{minipage}{\mythirdmaxsizeofcontenttable}\begin{myflushcenterinsidetable}
			JMC
		\end{myflushcenterinsidetable}\end{minipage} &
		\begin{minipage}{\mythirdmaxsizeofcontenttable}\begin{myflushcenterinsidetable}
			Jingbang
		\end{myflushcenterinsidetable}\end{minipage} & 
		\begin{minipage}{\mythirdmaxsizeofcontenttable}\begin{myflushcenterinsidetable}
			IM42EL-RS
		\end{myflushcenterinsidetable}\end{minipage} \\ \hline
		\multicolumn{1}{|l|}{\textbf{Dimensiones ($mm.$)}}& - & 57x57x80 & 86x86x67 & 50x50x100 \\ \hline
		\multicolumn{1}{|l|}{\textbf{Torque máximo ($Nm$)}}& 1.86 & 2.2 & 2.4 & 2.8 \\ \hline
		\multicolumn{1}{|l|}{\textbf{Diámetro de eje ($mm.$)}}& - & 8 & [14; 16] & 8 \\ \hline
		\multicolumn{1}{|l|}{\textbf{Peso ($kg$)}}& $<$2 & 1.2 & - & 1.5 \\ \hline
		\multicolumn{1}{|l|}{\textbf{Voltaje de alimentación ($V$)}}& 24 & Driver (24/48) & Driver (24/48) & 24 \\ \hline
		\multicolumn{1}{|l|}{\textbf{Corriente de fase ($A$)}}& - & 4 & 2 & 5 \\ \hline
		\multicolumn{1}{|l|}{\textbf{Temperatura operativa (°$C$)}}& - & - & [-20;60] & - \\ \hline
		\multicolumn{1}{|l|}{\textbf{Inductancia de fase ($mH$)}}& - & 1.8 & $\approx$9 & 2.0 \\ \hline
		\multicolumn{1}{|l|}{\textbf{Precio ($S/$)}}& - & 78.98 & 53.85 & 150.24 \\ \hline
	\end{tabular}
	\begin{myflushcenteraftertable}	
		Fuente: Imágenes de dominio público y elaboración propia. Hoja de datos técnica (\textit{Datasheet}) en el Anexo. \\
		Tasa de cambio de USD a PEN: S/ 3.59.
	\end{myflushcenteraftertable}
\end{mytable}

El modelo de motor a pasos del fabricante Jingbang, basado en Nema34 S/C, posee un torque de 2.4 que si bien es inferior a los 2.8 que ofrece el modelo ZL57HS09, este último triplica el precio del primero e es incluso menor que el modelo 57J1880-450, por lo que la relación $torque/precio$ es mayor en el modelo escogido.

%% NUEVO SECCION X.X.X.
\subsection{Selección de driver de motor a pasos}
	
Debido a las características únicas de cada servomotor, los fabricantes de cada marca recomiendan utilizar los drivers dedicados para sus componentes. Este trabajo no será la excepción, por lo que en la Tabla \ref{tab:driver del motor a pasos escogido} se muestra el driver del motor escogido en la subsección anterior.

\begin{mytable}[H]
	\footnotesize\centering
	\caption{Tabla comparativa de motores a pasos.}
	\label{tab:driver del motor a pasos escogido}
	\begin{tabular}{l|c|}		
		\cline{2-2}
		\multicolumn{1}{c|}{\textbf{}}            & \textbf{DM860H}  \\ \hline
		\multicolumn{1}{|l|}{\textbf{Figura}}     & 
		\begin{minipage}{\mythirdmaxsizeofcontenttable}
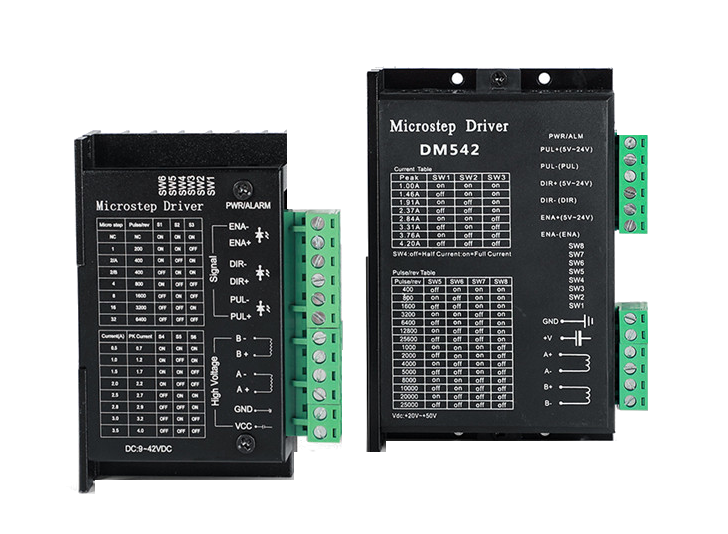
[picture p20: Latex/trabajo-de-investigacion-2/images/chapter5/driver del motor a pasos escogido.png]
			\centering \\ 
		\end{minipage} \\ \hline		
		\multicolumn{1}{|l|}{\textbf{Fabricante }} & Jingbang  \\ \hline
		\multicolumn{1}{|l|}{\textbf{Modelo de driver }} & 	Nema 34  \\ \hline
		\multicolumn{1}{|l|}{\textbf{Pico de corriente ($A$) }} & 7.2 \\ \hline
		\multicolumn{1}{|l|}{\textbf{Señal digital ($V$) }} & 5/ 24 \\ \hline
		\multicolumn{1}{|l|}{\textbf{Voltaje de alimentación ($V$) }} & [24; 110] \\ \hline
		\multicolumn{1}{|l|}{\textbf{Precio ($S/$)}} & 71.8  \\ \hline
	\end{tabular}
	\begin{myflushcenteraftertable}	
		Fuente: Imágenes de dominio público y elaboración propia. Hoja de datos técnica (\textit{Datasheet}) en el Anexo. \\
		Tasa de cambio de USD a PEN: S/ 3.59.
	\end{myflushcenteraftertable}
\end{mytable}
	
%% NUEVO SECCION X.X.X.
%% \subsection{Diseño de juego de compuertas programables}
%% Descripción.

%% NUEVO SUBSECCION X.X.X.
\section{Diseño de subsistema de traslado de truchas}

Las tuberías del sistema tienen como propósito abastecer de un flujo de agua constante a la máquina mientras está en funcionamiento. Cuatro canales de tuberías se abastecen de un flujo mediante este subsistema, accionado por bombas de agua y controlados por electroválvulas y sensores de caudal. Esto permite un correcto abastecimiento que no perjudique a las truchas. En las siguientes subsecciones se detalla el dimensionamiento de las tuberías, cálculo de caudales apropiados, selección de electroválvulas, su control asociado y selección de bombas de agua.

\begin{myfigure}[H]
	\footnotesize\centering
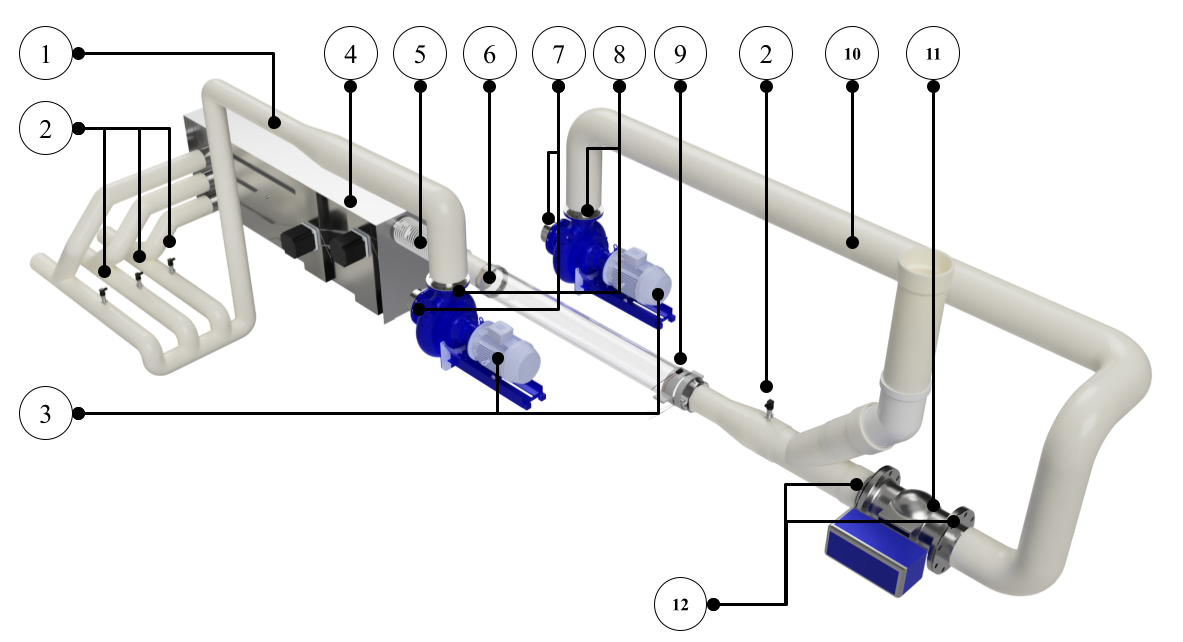
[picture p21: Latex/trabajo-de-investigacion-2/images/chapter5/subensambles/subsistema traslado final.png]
	
	\caption{Mecanismo de distribución de truchas}
	\begin{myflushcenter}
		Leyenda: (1) tubería secundaria; (2) sensores de presión; (3) bombas de agua; (4) distribuidora 1:3; (5) drenador de agua; (6) tubo transparente; (7) adaptador de entrada para bomba de agua; (8) adaptador de salida para bomba de agua; (9) sensor infrarrojo; (10) tubería principal; (11) electroválvula; (12) adaptador electroválvula. \\
		Fuente: Elaboración propia.
	\end{myflushcenter}
	\label{fig:subsistema de traslado}
\end{myfigure}
\vspace{-2.0em}

%% NUEVO SECCION X.X.X.
\subsection{Diseño de tuberías}
	
Las tuberías por las que las truchas transitarán en un solo sentido deben satisfacer los requerimientos mínimos técnicos: diámetro no menor al alto o ancho de una trucha. En el \textit{Estado del Arte}\footnote{Referencia de \cite{DiazVergara2020}.}, se observa que las truchas de 10 a 20 $cm.$ tienen un alto máximo de 60 a 90 $mm.$\footnote{Distancia máxima entre aleta superior e inferior más alejada del cuerpo. En truchas de 30 $cm.$ dicha distancia puede llegar hasta 135 $mm.$}

%% NUEVO SECCION X.X.X.
\subsection{Cálculo de caudales y selección de la bomba de agua}
	
En el diseño de las tuberías se toma en cuenta los siguientes parámetros: caudal necesario, viscosidad del fluido, presión operativa máxima, entre otros.\footnote{Extraído de \cite{INTECHGmbH2020}.} Se requiere un flujo laminar en el subsistema de procesamiento de imágenes, es decir, en la sección con tubo transparente en el que se captura fotogramas sobre las truchas en tránsito. Sin embargo, debido a los requerimientos del sistema en cuanto al diámetro de tuberías, se optará por un flujo de tipo turbulento pero horizontal\footnote{Flujo de agua dentro de una tubería que abarca toda la sección y genera pequeñas burbujas de aire.}. Entonces, para los valores de $D_{int}=3.5''=88.9 mm$ y $v=210 cm/s$ se calcula el número de Reynolds ($Re$) en la Ecuación \ref{eq:calculo de reynolds}.
	
\begin{myequation}\label{eq:calculo de reynolds}
	\begin{split}
		Re &= \frac{\rho*v*D_{int}}{\mu} \\
		Re &= \frac{999.7*2.1*0.0889}{0.001307} \\
		Re &= 142795.71 \approx 1.4x10^5
	\end{split}		
\end{myequation}

Donde: $\rho$ es la densidad del agua a 10 °C ($kg/m^3$), $v$ es la velocidad del fluido ($m/s$), $D_{int}$ es el diámetro interior de la tubería escogida ($m$), $\mu$ es la viscosidad dinámica del fluido a 10° C ($N*s/m^2$) y el número de Reynolds es adimensional. En la Figura \ref{fig:diagrama de moody} se muestra el diagrama de Moody.
	
\begin{myfigure}[H]
	\footnotesize\centering
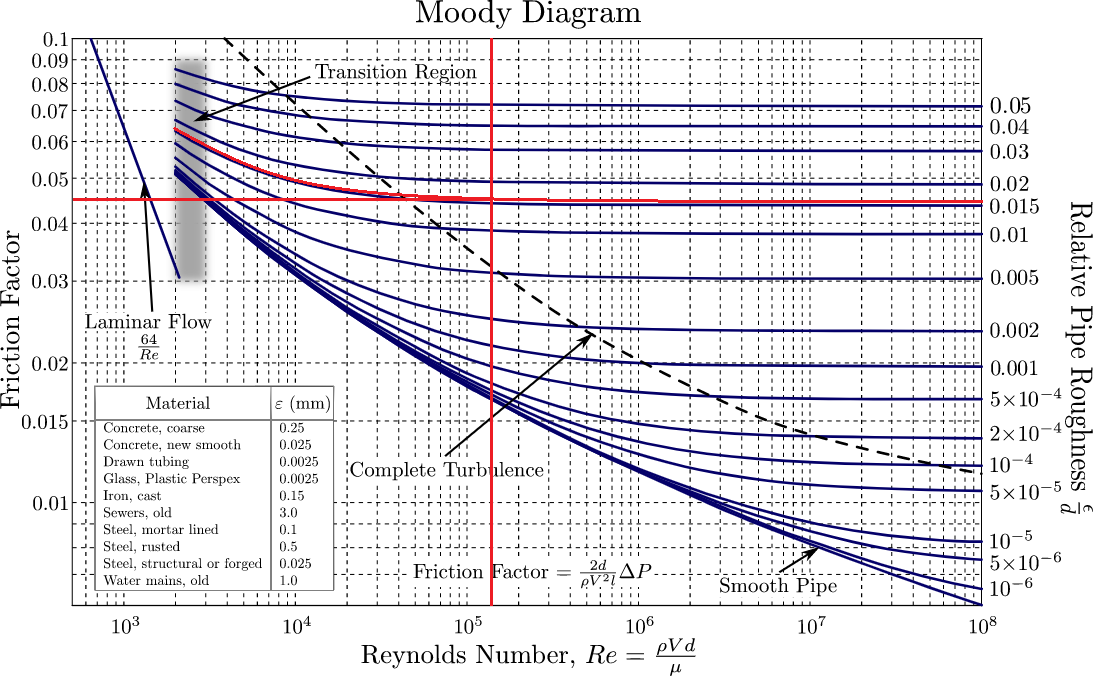
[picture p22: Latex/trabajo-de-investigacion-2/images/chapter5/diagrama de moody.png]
	
	\caption{Calculo de coeficiente de rozamiento usando diagrama de Moody.}
	\begin{myflushcenter}
		Fuente: \cite{Janna2015}.
	\end{myflushcenter}
	\label{fig:diagrama de moody}
\end{myfigure}

Luego, con $Re\approx1.4x10^5$ y sabiendo que la rugosidad de una tubería circular de PVC ($\varepsilon$) es $0.015 mm.$ podemos calcular el valor de rugosidad relativa ($\varepsilon/d=0.01687$) y el valor del coeficiente de rozamiento ($\lambda$).

Consecuentemente, el valor hallado para $\lambda$ es $\approx 0.046$. Sin embargo, para flujos turbulentos se emplea la ecuación de Colebrook–White, con la cual podemos hallarla con mayor precisión como se muestra en la Ecuación \ref{eq:calculo de coeficiente de fricción}.

\begin{myequation}\label{eq:calculo de coeficiente de fricción}
	\begin{split}
		\frac{1}{\sqrt{\lambda}} &= -2*log(\frac{2.51}{Re*\sqrt{\lambda}} + \frac{k}{3.71*d})
	\end{split}		
\end{myequation}

El valor de $\lambda$ es $0.0087$. Con este valor, podemos calcular la presión operativa necesaria para el sistema, que garantice el funcionamiento de la tubería como es esperado. El diagrama mostrado en la Figura \ref{fig:diagrama de tuberias} expone un recorrido horizontal del agua en el sistema, por lo que en la Ecuación \ref{eq:calculo de caudal} se calcula el caudal requerido a la salida.

\begin{myfigure}[H]
	\footnotesize\centering
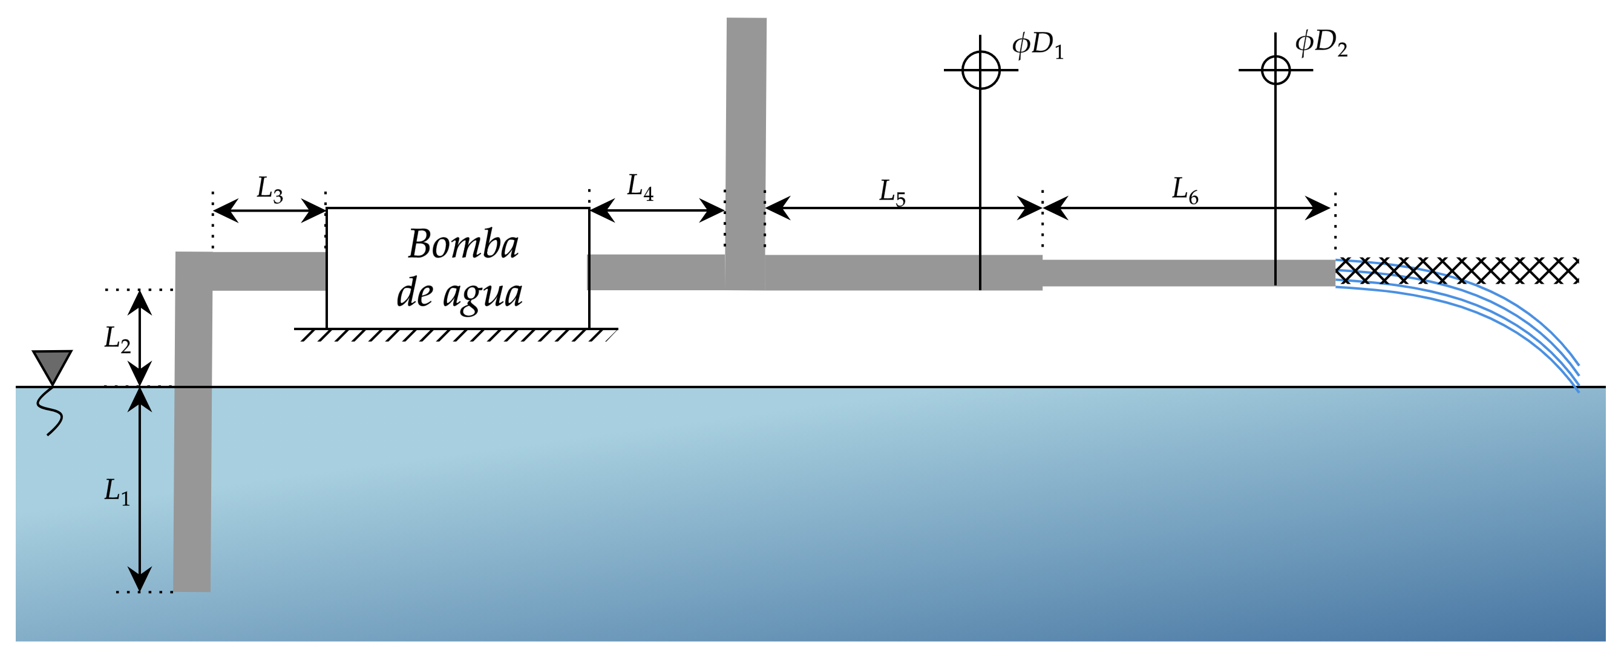
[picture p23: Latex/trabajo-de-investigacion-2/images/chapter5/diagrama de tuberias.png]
	
	\caption{Diagrama de tuberías.}
	\begin{myflushcenter}
		Fuente: Elaboración propia.
	\end{myflushcenter}
	\label{fig:diagrama de tuberias}
\end{myfigure}

\begin{myequation}\label{eq:calculo de caudal}
	\begin{split}
		Q &= A*v \\
		Q &= \frac{\pi*0.0762^2}{4}*2.1 \\
		Q &= 0.00957 \; (m^3/s) = 13.064 \; (L/s) \\
		Q_{req} &= 15 \; (L/s)
	\end{split}		
\end{myequation}

Dónde: $Q$ es el caudal ($m^3/s$) que fluye sobre una tubería circular de área $A$ ($m^2$) a una velocidad $v$ ($m/s$). Luego, en la Ecuación \ref{eq:calculo de pérdida de presion} se calcula la pérdida de carga en la tubería horizontal.

\begin{myequation}\label{eq:calculo de pérdida de presion}
	\begin{split}
		h_{L} &= h_{ma}+ h_{me} \\
		h_{L} &= f\frac{l}{D}\frac{v^2}{2g} + K_{L_{r}}\frac{v^2}{2g} + K_{L_{u}}\frac{v^2}{2g}\\
		h_{L} &= f\frac{l}{D}\frac{v^2}{2g} + K_{L_{r}}\frac{v^2}{2g} + 0.42(1-\frac{D_{2}}{D_{1}})\frac{v^2}{2g}\\
		h_{L} &= 0.0087\frac{2}{0.089}\frac{2.1^2}{2(9.81)} + 0.08\frac{2.1^2}{2(9.81)} + 0.42(1-\frac{0.089}{0.076})\frac{2.1^2}{2(9.81)}\\
		h_{L} &= 0.045 \; (m)
	\end{split}		
\end{myequation}

Dónde: $h_{L}$ es la pérdida de carga ($m$), $h_{ma}$ es la representación de las pérdidas de carga mayores, $h_{me}$ son las menores, $f$ es el factor de fricción , $l$ es la distancia horizontal ($m$), $D$ es el diámetro interior de la tubería ($m$), $v$ es la velocidad media del líquido ($m/s$), $g$ es la fuerza gravitacional ($m/s^2$) y $K_{L_{r}}$ es el coeficiente de pérdida por unión y $K_{L_{r}}$ es correspondiente a la reducción de diámetro. Entonces, la presión operativa puede ser calculada mediante la ecuación de Darcy–Weisbach como se muestra en la Ecuación \ref{eq:calculo de presion operativa}.

\begin{myequation}\label{eq:calculo de presion operativa}
	\begin{split}
		p_{b}-p_{s}&=\rho g(z_{2}-z{1})+\rho g h_{L} \\
		p_{b}-101.32 &= 441.31 \\
		p_{b}&= 542.63 \; (kPa) \\
		p_{b}&\approx 550 \; (kPa) \approx 80 \; (psi) \\			
	\end{split}		
\end{myequation}

Al momento de seleccionar bombas de agua, en la industria se suele usar un valor dependiente de la presión operativa: la altura de succión positiva neta ($NPSH$) que se define y calcula en la Ecuación \ref{eq:calculo de npsh}.

\begin{myequation}\label{eq:calculo de npsh}
	\begin{split}
		h_{NPSH} &= 2.31*\frac{p_{b}}{SG} \\
		h_{NPSH} &= 2.31*\frac{80}{9.804} \\
		h_{NPSH} &= 18.85 \; (m) \\
		h_{NPSH_{req}} &\approx 20 \; (m) \approx 65 \; (ft) \\
	\end{split}		
\end{myequation}

Dónde: $p_{b}$ es la presión operativa mínima requerida de la bomba de agua ($kPa$), $SG$ es el peso específico ($\gamma$)($kN/m^3$) del agua a 10 °C. Finalmente, se ingresa los requisitos mencionados al seleccionador de bombas de agua online de la empresa Hidrostal\footnote{Sitio web de seleccionador de bombas de agua: \href{https://www.hidrostal.com/pumpselector/}{https://www.hidrostal.com/pumpselector/}. Los grandes fabricantes suelen tener programas online para facilitar la selección de entre cientos de modelos.}: la empresa retorna un modelo de bomba de agua D03R-EHN con un motor DEYS4 que cumple con la certificación ISO 9906:2012 Grado 3B\footnote{Más detalles en \href{https://www.iso.org/standard/41202.html}{https://www.iso.org/standard/41202.html}.}. Además, mencionar que el consumo de potencia es de 2.1 $kW$, trabaja a una velocidad de 1435 $rpm$ con una eficiencia del $69.8\%$ y que puede variar el caudal de 10 a 24 $L/s$.\footnote{Hoja de datos (Datasheet) en el Anexo.}

%% NUEVO SECCION X.X.X.
\subsection{Selección de las electroválvulas}

Los valores límites que se tendrían que controlar mediante las electroválvulas pertenecen al rango $[0;15]$ $(L/s)$. Las electroválvulas cumplen la función de controlar el actuador solenoide, mariposa o de globo de manera automática para regular el caudal de agua dentro de las tuberías del sistema. En la Tabla \ref{tab:tabla comparativa de electrovalvulas} se muestran algunos modelos comerciales que cumplen con estos requerimientos.

\begin{mytable}[H]
	\footnotesize\centering
	\caption{Tabla comparativa de electroválvulas}
	\label{tab:tabla comparativa de electrovalvulas}
	\begin{tabular}{l|c|c|c|c|}
		\cline{2-5}
		\multicolumn{1}{c|}{\textbf{}} & \textbf{\begin{tabular}[c]{@{}c@{}}Requisitos\\ mínimos\end{tabular}} & \textbf{2W} & \textbf{CTB100} & \textbf{400P} \\ \hline
		\multicolumn{1}{|l|}{\textbf{Figura}}   & -   
		&
		\begin{minipage}{\mythirdmaxsizeofcontenttable}
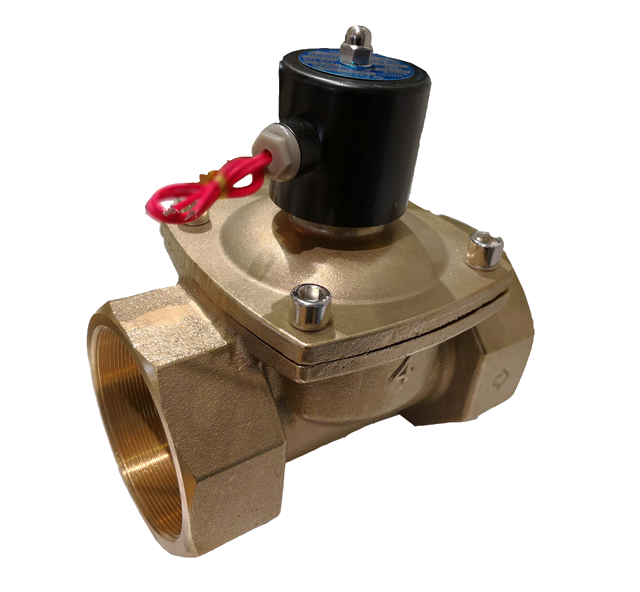
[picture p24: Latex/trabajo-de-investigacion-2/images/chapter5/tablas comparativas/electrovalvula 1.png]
			\centering \\ 
			%\begin{myflushcenter}
			%	{\footnotesize Nombre imagen}
			%\end{myflushcenter}
		\end{minipage} 
		&
		\begin{minipage}{\mythirdmaxsizeofcontenttable}
			\centering \\ 
			%\begin{myflushcenter}
			%	{\footnotesize Nombre imagen}
			%\end{myflushcenter}
		\end{minipage} 
		&
		\begin{minipage}{\mythirdmaxsizeofcontenttable}
			\centering \\ 
			%\begin{myflushcenter}
			%	{\footnotesize Nombre imagen}
			%\end{myflushcenter}
		\end{minipage}	\\ \hline
		\multicolumn{1}{|l|}{\textbf{Fabricante}} & - & Xhnotion & TF & AFK \\ \hline
		\multicolumn{1}{|l|}{\textbf{Voltaje de alimentación ($V$)}} & 24 & 24 & 12/24/48 & 24 \\ \hline
		\multicolumn{1}{|l|}{\textbf{Diámetro interno ($in.$)}} & - & Hasta 4 & Hasta 7 & Hasta 4 \\ \hline
		\multicolumn{1}{|l|}{\textbf{Líquidos}} & Agua & Aire/Agua/Aceite & Gas/Agua & Agua \\ \hline
		\multicolumn{1}{|l|}{\textbf{Material}} & - & Latón & Plás./Ac. Inox./Hierro & Plás. + NBR\\ \hline
		\multicolumn{1}{|l|}{\textbf{Tipo de conexión}} & - & Hembra & Hembra & Macho/Hembra \\ \hline
		\multicolumn{1}{|l|}{\textbf{Presión máxima operativa ($kPa$)}} & 550 & - & 4000 & 1400 \\ \hline
		\multicolumn{1}{|l|}{\textbf{Tipo}} & - & Solenoide & Mariposa & Solenoide \\ \hline
		\multicolumn{1}{|l|}{\textbf{Certificados}} & - & ISO 9001:2008 & - & - \\ \hline
		\multicolumn{1}{|l|}{\textbf{Consumo de potencia ($W$)}} & - & - & 100 & - \\ \hline
		\multicolumn{1}{|l|}{\textbf{Temperatura operativa (°$C$)}} & [-10; 40] & [-25; 60] & [-25; 60] & [-20 ; 43] \\ \hline
		\multicolumn{1}{|l|}{\textbf{Peso aproximado ($kg$)}} & - & - & 12 & - \\ \hline
		\multicolumn{1}{|l|}{\textbf{Precio ($S/$)}} & - & 244.12 & 287.20 & 642.61 \\ \hline		
	\end{tabular}	
	\begin{myflushcenteraftertable}			
		Fuente: Imágenes de dominio público y elaboración propia. Hoja de datos técnica (\textit{Datasheet}) en el Anexo. \\
		Tasa de cambio de USD a PEN: S/ 3.59.
	\end{myflushcenteraftertable}
\end{mytable}

Se escoge la válvula del fabricante TF modelo CTB100 debido a que cuenta con un control más complejo al modelo 2W, que si bien su diseño es más simple el control se desplaza al microprocesador. Además, esta electroválvula cumple con el objetivo de regular la apertura de la compuerta que impide el paso de caudal de agua.

%% NUEVO SECCION X.X.X.
\subsection{Selección de sensores de presión}

Los sensores de presión se usan para medir el caudal de forma indirecta y poder controlar la electroválvula. En la sección de control se explica a detalle este proceso. En la Tabla \ref{tab:tabla comparativa de sensores de presion} se presenta una comparación técnica de los sensores de presión.

\begin{mytable}[H]
 	\footnotesize\centering
 	\caption{Tabla comparativa de sensores de presión}
 	\label{tab:tabla comparativa de sensores de presion}
 	\begin{tabular}{l|c|c|c|c|}
 		\cline{2-5}
 		\multicolumn{1}{c|}{\textbf{}} & \textbf{\begin{tabular}[c]{@{}c@{}}Requisitos\\ mínimos\end{tabular}} & \textbf{FST800-211A} & \textbf{WNK80MA} & \textbf{T2000-191202} \\ \hline
 		\multicolumn{1}{|l|}{\textbf{Figura}}   & -   
 		&
 		\begin{minipage}{\mythirdmaxsizeofcontenttable}
 			\centering \\ 
 			%\begin{myflushcenter}
 			%	{\footnotesize Nombre imagen}
 			%\end{myflushcenter}
 		\end{minipage} 
 		&
 		\begin{minipage}{\mythirdmaxsizeofcontenttable}
 			\centering \\ 
 			%\begin{myflushcenter}
 			%	{\footnotesize Nombre imagen}
 			%\end{myflushcenter}
 		\end{minipage} 
 		&
 		\begin{minipage}{\mythirdmaxsizeofcontenttable}
 			\centering \\ 
 			%\begin{myflushcenter}
 			%	{\footnotesize Nombre imagen}
 			%\end{myflushcenter}
 		\end{minipage}	\\ \hline	
 		\multicolumn{1}{|l|}{\textbf{Fabricante}} & - & FirstRate & WNK & LEFOO \\ \hline
 		\multicolumn{1}{|l|}{\textbf{Voltaje de alimentación ($V$)}} & 12 & [9; 30] & 3.3/5/12/24 & [10; 30] \\ \hline
 		\multicolumn{1}{|l|}{\textbf{Voltaje de salida ($V$)}} & - & [0.5; 4.5] & [1; 5] & [0; 10] \\ \hline
 		\multicolumn{1}{|l|}{\textbf{Corriente de salida ($mA$)}} & - & [4; 20] & [4; 20] & [4; 20] \\ \hline
 		\multicolumn{1}{|l|}{\textbf{Temperatura operativa (°$C$)}} & [-10; 40] & [-40; 85] & [-20; 85] & [-10 ; 80] \\ \hline
 		\multicolumn{1}{|l|}{\textbf{Protección ($IP$)}} & - & $IP65$ & $IP65$ & $IP65$ \\ \hline
 		\multicolumn{1}{|l|}{\textbf{Certificados}} & - & CE RoHS & CE RoHS \& ISO & ECM \\ \hline
 		\multicolumn{1}{|l|}{\textbf{Precisión ($Pa$)}} & - & - & 5000 & - \\ \hline
 		\multicolumn{1}{|l|}{\textbf{Presión máxima ($kPa$)}} & 550 & [100; 60000] & [20; 25000] & [20; 25000] \\ \hline
 		\multicolumn{1}{|l|}{\textbf{Peso aproximado ($kg$)}} & - & 0.1 & 0.1 & - \\ \hline
 		\multicolumn{1}{|l|}{\textbf{Precio ($S/$)}} & - & 78.98 & 43.08 & 89.75 \\ \hline		
 	\end{tabular}	
 	\begin{myflushcenteraftertable}			
 		Fuente: Imágenes de dominio público y elaboración propia. Hoja de datos técnica (\textit{Datasheet}) en el Anexo. \\
 		Tasa de cambio de USD a PEN: S/ 3.59.
 	\end{myflushcenteraftertable}
\end{mytable}

El sensor de presión WNK80MA de la empresa manufacturera WNK es escogido porque representa los requisitos mínimos a un menor precio, sin escatimar en características como nivel de protección, certificados y máxima presión que soporta el componente.	

%----------------------------------------------------------------------------------------
%	Capítulo 5 
%----------------------------------------------------------------------------------------
\pagestyle{myportland}
%\pagenumbering{arabic}
\doublespacing
\chapter[\quad\quad\quad\quad ----- Diseño de subsistema de procesamiento de imágenes]{\\ Diseño de subsistema de procesamiento de imágenes}
\thispagestyle{myportland}

Este subsistema consiste obtener una serie de imágenes de una trucha en tránsito e indicar al sistema a dónde debería dirigirse una trucha determinada. El subsistema debe clasificar y contar truchas, con dicha finalidad necesita de la selección de una cámara y generar el ambiente adecuado para obtener las imágenes. Explicado los objetivos del subsistema, en las siguientes líneas se detalla: la selección del sensor infrarrojo, la selección de cámara estéreo, la selección de iluminación adecuada y la selección de algoritmos. %En la Figura \ref{fig:subsistema de procesamiento de imagenes} se enumera los principales componentes: 

\begin{myfigure}[H]
	\footnotesize\centering
	
	\caption{Subsistema de procesamiento de imágenes}
	\begin{myflushcenter}
		Leyenda: (1) sensor de presión; (2) reductor de tubería; (3) sensor infrarrojo; (4) adaptador y sensor infrarrojo; (5) cámara estéreo a cierta distancia perpendicular; (6) juego de espejos; (7) tubo transparente.\\
		Fuente: Elaboración propia.
	\end{myflushcenter}
	\label{fig:subsistema de procesamiento de imagenes}
\end{myfigure}

\vspace{-2.0em}
 
%% NUEVO SECCION X.X.
\section{Selección del sensor infrarrojo}

El sensor infrarrojo tiene como objetivo activar el algoritmo de detección y conteo de truchas por un determinado periodo de tiempo con la finalidad de evitar un sobre uso de los recursos computacionales. El sensor infrarrojo está unos centímetros antes de la parte que la cámara captura y su posición es como se muestra en el globo número 4 con su adaptador para la tubería en la Figura \ref{fig:subsistema de procesamiento de imagenes}.

%\begin{myfigure}[H]
%	\footnotesize\centering
%	\includegraphics[width=1\textwidth]{chapter5/posicion sensor infrarrojo.png}
%	\caption{Posicionamiento del sensor infrarrojo}
%	\begin{myflushcenter}
%		Fuente: Elaboración propia.
%	\end{myflushcenter}
%	\label{fig:posicion sensor infrarrojo}
%\end{myfigure}

Ya que los haces de luz cambian de dirección debido a la refracción\footnote{\cite{Hecht2017}.}, cuando varía de un medio a otro, se calcula esta desviación para la adecuada detección de objetos que pasen por la tubería. La representación gráfica de la situación se expone en la Figura \ref{fig:analisis de posicion de luz infrarroja}.

\begin{myfigure}[H]
	\footnotesize\centering
	
	\caption{Análisis de posición de luz infrarroja}
	\begin{myflushcenter}
		Fuente: Elaboración propia.
	\end{myflushcenter}
	\label{fig:analisis de posicion de luz infrarroja}
\end{myfigure}

El problema se muestra en la Figura \ref{fig:calculo de posicion de luz infrarroja}. Cabe mencionar que se conocen los siguientes valores $n_{PMMA}=1.5$\footnote{Propiedades ópticas mostradas en la Tabla \ref{tab:tabla comparativa de propiedades entre pmma vs pvdf vs petg}. \cite{Berins1991}}, $n_{aire}\approx1$, $n_{agua}=1.33$\footnote{Índices de refracción: \cite{Hecht2017}.}, $d_{1}=d_{2}=10 mm.$, $e=3 mm.$ y $d_{int}=85 mm.$ ,y se asume, para simplificar el problema, la emisión de la luz como proveniente de un punto único ($S$).

\begin{myfigure}[H]
	\footnotesize\centering
	
	\caption{Cálculo de posición de luz infrarroja}
	\begin{myflushcenter}
		Fuente: Elaboración propia.
	\end{myflushcenter}
	\label{fig:calculo de posicion de luz infrarroja}
\end{myfigure}

Para el cálculo de desviación de los haces de luz se emplea la ley de refracción, matemáticamente mostrada en la Ecuación \ref{eq:ecuacion de snell}. Donde: $\theta_{i}$ es el ángulo de incidencia respecto a la normal del primer medio, $\theta_{t}$ es el ángulo de refracción respecto a la normal.

\begin{myequation}\label{eq:ecuacion de snell}
	\begin{split}
		n_{i}*sin(\theta_{i})&=n_{t}*sin(\theta_{t})
	\end{split}		
\end{myequation}

En la Figura \ref{fig:calculo distancia maxima de desviacion de haz de luz en condiciones ideales} se analiza el caso crítico cuando $\theta_{1}\approx5^\circ$. Con la Ecuación \ref{eq:ecuacion de snell} se puede calcular las distancias de desviación por refracción. Por ejemplo, En la Ecuación \ref{eq:calculo distancia maxima de desviacion de haz de luz en condiciones ideales} el valor de $h_{x}$ es la distancia proyectada: $h_{x}=d_{x}*tan(\theta_{x})$.

\begin{myfigure}[H]
	\footnotesize\centering
	
	\caption{Cálculo de distancia máxima de desviación de haz de luz en condiciones ideales.}
	\begin{myflushcenter}
		Fuente: Elaboración propia.
	\end{myflushcenter}
	\label{fig:calculo distancia maxima de desviacion de haz de luz en condiciones ideales}
\end{myfigure}

\begin{myequation}\label{eq:calculo distancia maxima de desviacion de haz de luz en condiciones ideales}
	\begin{split}
		H_{max}&=h_{1}+h_{2}+h_{3}+h_{4}+h_{5} \\
		H_{max}&=10*tan(\theta_{1})+3*tan(\theta_{2})+85*tan(\theta_{3})+3*tan(\theta_{4})+10*tan(\theta_{5}) \\
		H_{max}&=10*tan(5^\circ)+3*tan(3.33^\circ)+85*tan(3.76^\circ)+3*tan(3.33^\circ)+10*tan(5^\circ) \\
		H_{max}&=7.685 mm.
	\end{split}		
\end{myequation}

Para una óptima recepción se propone llegar como mínimo 75\% de haces de luz. Esto quiere decir que del diámetro ideal del dispositivo receptor debe ser de 15.4 mm y el óptimo 13.33 mm.\footnote{$d_{ideal-receptor}=2*H_{max}=15.4 mm.$ y $d_{75\%-receptor}=\sqrt{0.75*15.4^2}=13.33 mm.$ } Finalmente, los requerimientos mínimos que debe tener el sensor infrarrojo óptimo y comparaciones técnicas de los dispositivos comerciales que cumplen con los requerimientos se muestran en la Tabla \ref{tab:tabla comparativa de sensores infrarrojos}.

\begin{mytable}[H]
	\footnotesize\centering
	\caption{Tabla comparativa de sensores infrarrojos.}
	\label{tab:tabla comparativa de sensores infrarrojos}
	\begin{tabular}{l|c|c|c|c|}
		\cline{2-5}
		\multicolumn{1}{c|}{\textbf{}}            & \textbf{\begin{tabular}[c]{@{}c@{}}Requisitos\\ mínimos\end{tabular}} &
		\multicolumn{1}{|l|}{
			\begin{minipage}{\mythirdmaxsizeofcontenttable}	
				\begin{myflushcenterinsidetable}
					\textbf{HD-DS25 CM-3MM}
				\end{myflushcenterinsidetable}				
			\end{minipage}
		}&
		\multicolumn{1}{|l|}{		
			\begin{minipage}{\mythirdmaxsizeofcontenttable}	
				\begin{myflushcenterinsidetable}
					\textbf{QT50CM}
				\end{myflushcenterinsidetable}				
			\end{minipage}	
		}&
		\multicolumn{1}{|l|}{			
			\begin{minipage}{\mythirdmaxsizeofcontenttable}	
				\begin{myflushcenterinsidetable}
					\textbf{GP2Y0A 21YK0F}
				\end{myflushcenterinsidetable}				
			\end{minipage}
		}  \\ \hline
		\multicolumn{1}{|l|}{\textbf{Figura}} & - 
		&		  
		\begin{minipage}{\mythirdmaxsizeofcontenttable}
			\centering \\ 
			%\begin{myflushcenter}
			%	{\footnotesize Nombre imagen}
			%\end{myflushcenter}
		\end{minipage}
		&		  
		\begin{minipage}{\mythirdmaxsizeofcontenttable}
			\centering \\ 
			%\begin{myflushcenter}
			%	{\footnotesize Nombre imagen}
			%\end{myflushcenter}
		\end{minipage}
		&  
		\begin{minipage}{\mythirdmaxsizeofcontenttable}
			\centering \\ 
			%\begin{myflushcenter}
			%	{\footnotesize Nombre imagen}
			%\end{myflushcenter}
		\end{minipage}\\ \hline
		\multicolumn{1}{|l|}{\textbf{Fabricante}} 
		& - & Adafruit & Adafruit & SHARP\\ \hline
		\multicolumn{1}{|l|}{
			\begin{minipage}{\myforthmaxsizeofcontenttable}	
				\textbf{Tipo de comunicación}
			\end{minipage}
		} & - & [0;VCC] & [0;VCC] & Analógico         \\ \hline
		\multicolumn{1}{|l|}{
			\begin{minipage}{\myforthmaxsizeofcontenttable}	
				\textbf{Área mínima circular de receptor ($mm^2$)}
			\end{minipage}
		} & 15.4 & 28.27 & 78.54 & 162.86         \\ \hline
		\multicolumn{1}{|l|}{
			\begin{minipage}{\myforthmaxsizeofcontenttable}	
				\textbf{Ángulo de visión/recepción (°)}
			\end{minipage}
		} & 5 & 10 & 10 & -         \\ \hline
		\multicolumn{1}{|l|}{
			\begin{minipage}{\myforthmaxsizeofcontenttable}	
				\textbf{Distancia de detección ($mm.$)}
			\end{minipage}
		} & 170 & [0;250] & [0;500] & [100;800] \\ \hline
		\multicolumn{1}{|l|}{
			\begin{minipage}{\myforthmaxsizeofcontenttable}	
				\textbf{Longitud de onda infrarroja recomendada ($nm$)}
			\end{minipage}
		} & 850 & - & - & 870$\pm$70 \\ \hline
		\multicolumn{1}{|l|}{
			\begin{minipage}{\myforthmaxsizeofcontenttable}	
				\textbf{Voltaje operativo VCC ($V$)}
			\end{minipage}
		} & 5  & [3.0;5.5] & [3.0;5.5] & [4.5;5.5]         \\ \hline
		\multicolumn{1}{|l|}{
			\begin{minipage}{\myforthmaxsizeofcontenttable}	
				\textbf{Consumo de corriente ($mA$)}
			\end{minipage}
		} & -  & 100 & 100 & 30         \\ \hline
		\multicolumn{1}{|l|}{
			\begin{minipage}{\myforthmaxsizeofcontenttable}	
				\textbf{Temperatura operativa (°$C$)}
			\end{minipage}
		} & [-10;40] & [-25;60] & [-25;60] & [-10;60] \\ \hline
		\multicolumn{1}{|l|}{
			\begin{minipage}{\myforthmaxsizeofcontenttable}	
				\textbf{Precio ($S/$)}
			\end{minipage}
		} & - & 7.00 & 23.32 & 53.68 \\ \hline
	\end{tabular}
	\begin{myflushcenteraftertable}	
		Fuente: Marktech Optoelectronics y elaboración propia. Hoja de datos técnica (\textit{Datasheet}) en el Anexo.\\
		Tasa de cambio de USD a PEN: S/ 3.59.
	\end{myflushcenteraftertable}
\end{mytable}

De la Tabla \ref{tab:tabla comparativa de sensores infrarrojos} se visualiza que las principales diferencias de las alternativas se basan en el área de los actuadores infrarrojos del emisor y su sensado en el receptor, y la distancia máxima que puede detectar. La distancia máxima a medir en el sistema, es el diámetro de la tubería que no es mayor a $4 \; in. \approx 100 \; mm.$ adicional al mecanismo que los posicionará no debería exceder de los $170 \; mm.$. Entonces, se escoge el modelo HD-DS25CM-3MM que cumple con estas características al menor precio.

%% NUEVO SECCION X.X.
\section{Selección de cámaras} 

En el sistema se emplea dos cámaras con distintos requerimientos técnicos. Por un lado, una cámara estéreo se encarga de capturar imágenes que van a ser procesadas por algoritmos de detección y conteo de truchas. Por otro lado, una cámara normal registra la trayectoria de las truchas que en la distribución de estas a los canales de salida definidos por los algoritmos. 

%% NUEVO SECCION X.X.X.
\subsection{Cálculo de distancias apropiadas de las cámaras}

El área que se debe captar sobre el proceso, sin las tuberías transparentes, se representan  en una vista frontal y de perfil en la Figura \ref{fig:distancia entre juego de espejos y camara estereo}. Donde: $d$ es la distancia entre el juego de espejos y la cámara, $\alpha$ es el HDFV\footnote{Campo de visión horizontal.}, $\beta$ es el VDFV\footnote{Campo de visión vertical.}, $A$ es la altura del área proyectada y $L$ es la largo del área proyectada del juego de espejos.

\begin{myfigure}[H]
	\footnotesize\centering
	
	\caption{Distancia entre juego de espejos y cámara estéreo}
	\begin{myflushcenter}
		Fuente: Elaboración propia.
	\end{myflushcenter}
	\label{fig:distancia entre juego de espejos y camara estereo}
\end{myfigure}

De la geometría se obtiene los valores de $\alpha$ y $\beta$, que dependen de las otras variables. El posicionamiento de la cámara ($d$) estéreo estará sujeto a sus valores de HDFV y VDFV como se muestra en la Ecuación \ref{eq:calculo beta de distancia entre espejos y camara estereo} y \ref{eq:calculo alfa de distancia entre espejos y camara estereo}, respectivamente.
	
\begin{myfigure}[H]
	\footnotesize\centering
	
	\caption{Cálculo de distancia apropiada para la cámara estéreo}
	\begin{myflushcenter}
		Fuente: Elaboración propia.
	\end{myflushcenter}
	\label{fig:calculo de distancia entre espejos y camara estereo}
\end{myfigure}

\begin{myequation}\label{eq:calculo alfa de distancia entre espejos y camara estereo}
	\begin{split}
		tan(\alpha_{min}/2)&=\frac{A/2}{d}\\
		\alpha_{min}&=2*atan(\frac{A}{2*d})\\
	\end{split}		
\end{myequation}

\begin{myequation}\label{eq:calculo beta de distancia entre espejos y camara estereo}
	\begin{split}
		tan(\beta_{min}/2)&=\frac{L/2}{d}\\
		\beta_{min}&=2*atan(\frac{L}{2*d})\\
	\end{split}		
\end{myequation}

%% NUEVO SECCION X.X.X.
\subsection{Cálculo de cuadros por segundo (fps) necesarios para la cámara estéreo}

Con el objetivo de calcular los cuadros por segundo necesarios, se muestra en la Figura \ref{fig:grafica tamano y velocidad de nado trucha arcoiris} una aproximación lineal entre el peso ($g$) y la velocidad de nado ($cm/s$) de una trucha de la especie en cuestión. Dicho nado es contracorriente y de forma aleatoria, en el presente estudio se utiliza dicha información para simplificar el análisis\footnote{Es necesario elaborar un estudio detallado de la velocidad de nado dentro de sistemas acorde al propuesto. El estudio  \cite{Borisovich2016} asegura que se pudo capturar imágenes a 25 Hz de una tubería de 180 $mm.$ de diámetro a una velocidad de 5-8 $m/s$}.

\begin{myfigure}[H]
	\footnotesize\centering
	
	\caption{Aproximación lineal de la relación entre peso y la velocidad de nado de truchas arcoíris}
	\begin{myflushcenter}
		Fuente: \cite{Fry1970}
	\end{myflushcenter}
	\label{fig:grafica tamano y velocidad de nado trucha arcoiris}
\end{myfigure}	

En la Ecuación \ref{eq:ecuacion relacion tamano y velocidad de nado de trucha arcoiris} se muestra la relación (regresión lineal) entre \textit{X: peso de la trucha ($g$)} e \textit{Y: velocidad de nado ($cm/s$)} con un error \textit{Z= $0.033$}. 

\begin{myequation} \label{eq:ecuacion relacion tamano y velocidad de nado de trucha arcoiris}
	Y\approx0.2828*X+48
\end{myequation}
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

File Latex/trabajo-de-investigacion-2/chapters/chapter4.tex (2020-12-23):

%----------------------------------------------------------------------------------------
%	Capítulo 4
%----------------------------------------------------------------------------------------

\pagestyle{myportland}
%\pagenumbering{arabic}
\doublespacing
\chapter[\quad\quad\quad\quad ----- Antecedentes]{\\Antecedentes}
\thispagestyle{myportland}

En este capítulo se explica la procedencia del diseño junto con su propósito en la descripción del sistema conceptual. Luego, se explaya el objetivo general y los objetivos específicos del presente trabajo, el alcance del estudio y la metodología usada.

\begin{myfigure}[H]
	\centering
	
	\caption{Dibujo del concepto óptimo}
	\begin{myflushcenter}
		Fuente: \cite{DiazVergara2020}.
	\end{myflushcenter}
	\label{fig:concepto optimo dibujo y virtual}
\end{myfigure}

\vspace{-2.0em}

%% NUEVA SECCIÓN X.X
\section{Problemática}
%\label{sec:descripcion del sistema conceptual}

El presente trabajo es la continuación del trabajo \textit{"Diseño conceptual de clasificadora y contadora de truchas arcoíris (Oncorhynchus mykiss) de 10 a 20 centímetros para la crianza de truchas en la Laguna de Paucarcocha"}\footnote{\cite{DiazVergara2020}}: parte del diseño conceptual y, en el presente trabajo, se desarrolla el diseño integral. Dicho diseño conceptual se enfoca en elaborar un sistema que "reduzca la mortandad presente en el proceso de clasificación manual". En la Figura \ref{fig:concepto optimo dibujo y virtual} se muestra el bosquejo del concepto de solución desarrollado en dicho trabajo y también una versión 3D sobre dicho bosquejo sin algunos componentes. El presente trabajo continua en brindar una solución de ingeniería que logre disminuir las consecuencias de un trabajo manual con maquinaria semi-automática.

%% NUEVA SECCIÓN X.X
\section{Alcance}

El presente estudio abarca el diseño integral de la máquina clasificadora y contadora de truchas arcoíris (CCT) con enfoque en el costo para disminuir la mortalidad en el proceso de clasificación y conteo de truchas en lagos o lagunas. Asimismo, unifica tecnologías de la última generación para automatizar el proceso mencionado. El diseño integral abarca el diseño de la máquina centrado en los operarios, el uso de tecnologías recientes para brindar un sistema que unifica acceso mediante aplicaciones, procesamiento offline e interacción mediante aplicaciones móviles. Además, este diseño pretende ser la base de un prototipo y posterior máquina comercializable para mejorar la producción de salmones en lagos y lagunas en el Perú. Este sistema esta dentro de los objetivos globales de desarrollo sostenible establecidos por la ONU\footnote{Las Naciones Unida. Ver objetivos en \href{https://www.un.org/sustainabledevelopment/es/objetivos-de-desarrollo-sostenible/}{https://www.un.org/sustainabledevelopment/es/objetivos-de-desarrollo-sostenible/}}: noveno objetivo que trata sobre industria, innovación e infraestructura, en este caso en el sector acuícola.

%% NUEVO SUBSECCION X.X
\section{Objetivos}

Se presenta el objetivo general y los objetivos específicos del presente trabajo.

%% NUEVA SUB-SUB-SECCION X.X.X
\subsection{Objetivo general}

Realizar el diseño integral (de ingeniería) de una máquina clasificadora y contadora de truchas arcoíris (CCT) de 15 a 20 centímetros a partir del diseño conceptual previo\footnote{Diseño conceptual extraído de \cite{DiazVergara2020}}.

%% NUEVA SUB-SUB-SECCION X.X.X
\subsection{Objetivos específicos}
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

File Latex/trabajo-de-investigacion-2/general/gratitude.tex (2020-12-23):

%----------------------------------------------------------------------------------------
%	Agradecimientos
%----------------------------------------------------------------------------------------

\newpage
\clearpage{\pagestyle{empty}\cleardoublepage}
%\doublespacing
\newpage

\chapter*{\centering \large Agradecimientos}
\addcontentsline{toc}{chapter}{Agradecimientos}
\markboth{Agradecimientos}{Agradecimientos}
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

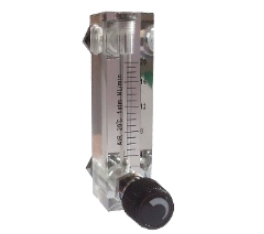
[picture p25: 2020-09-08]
Latex/trabajo-de-investigacion-1/images/chapter3/matriz/rotametro electronico.png

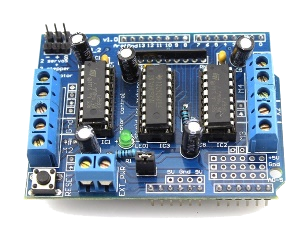
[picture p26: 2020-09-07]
Latex/trabajo-de-investigacion-1/images/chapter3/matriz/tarjeta electronica para control de motores.png

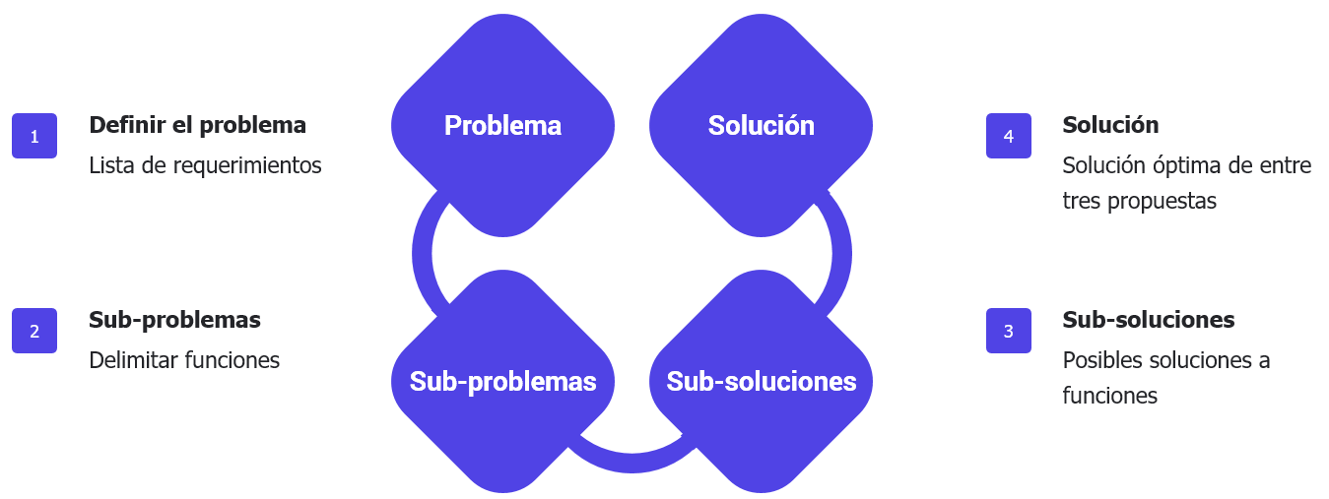
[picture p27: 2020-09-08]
Latex/trabajo-de-investigacion-2/images/chapter5/estado diseno solucion.png

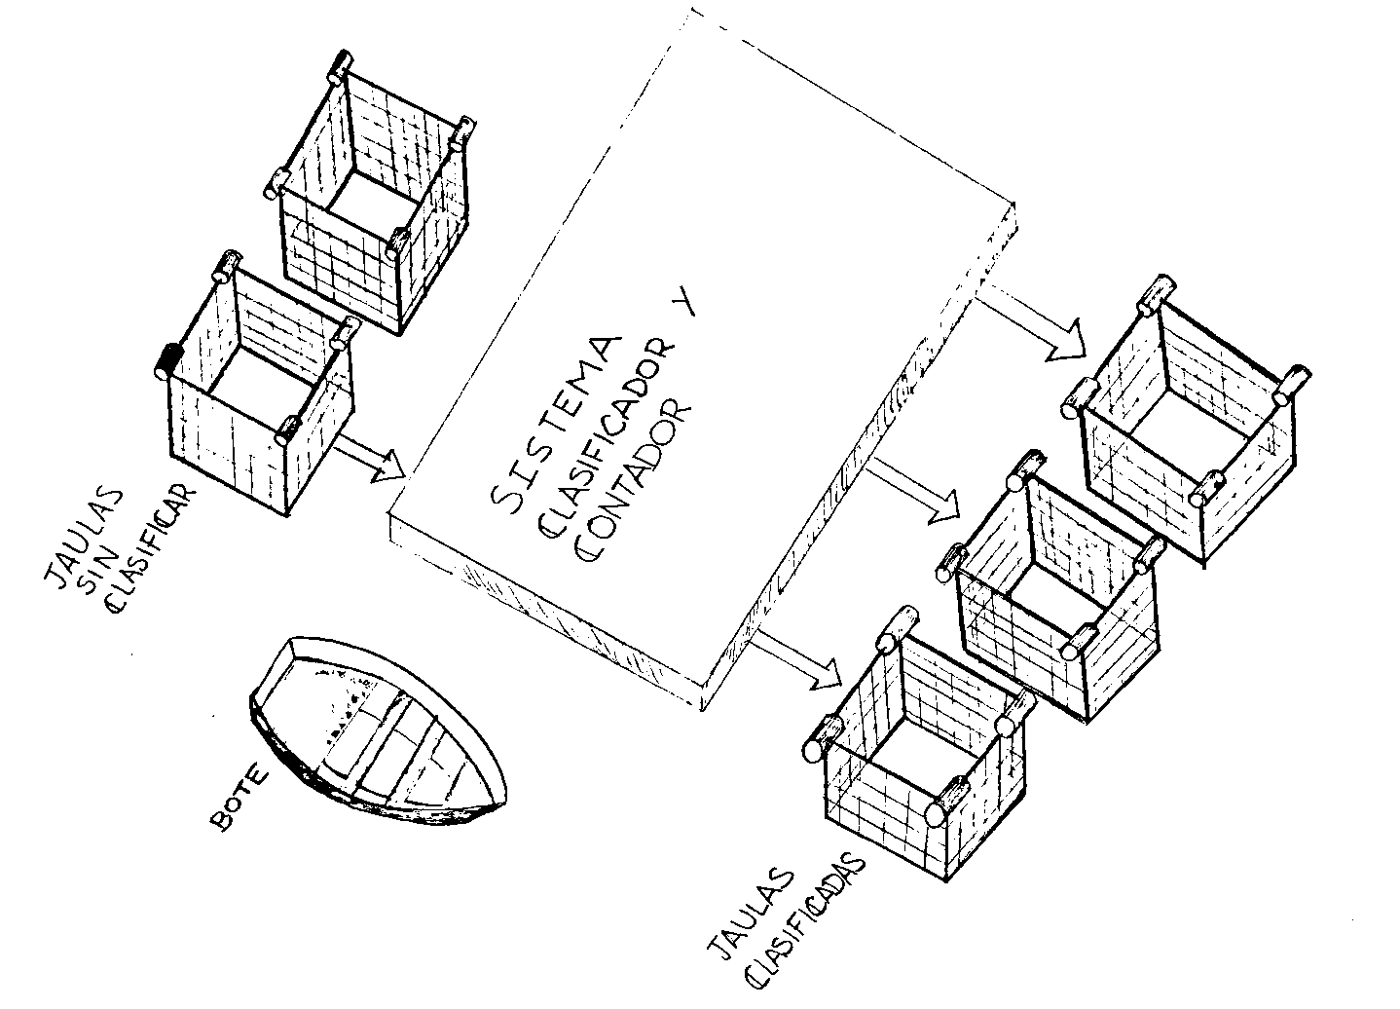
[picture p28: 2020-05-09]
Latex/trabajo-de-investigacion-1/images/chapter3/dibujo conceptual de la problematica.png

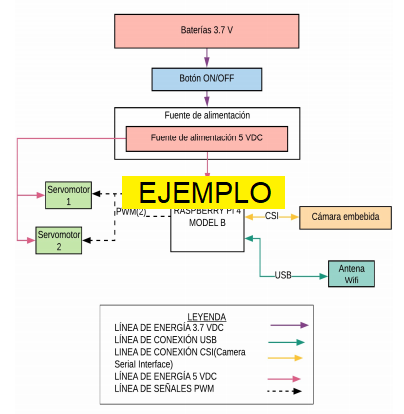
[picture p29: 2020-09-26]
Latex/trabajo-de-investigacion-2/images/chapter5/ejemplo arquitectura de hardware del sistema.png

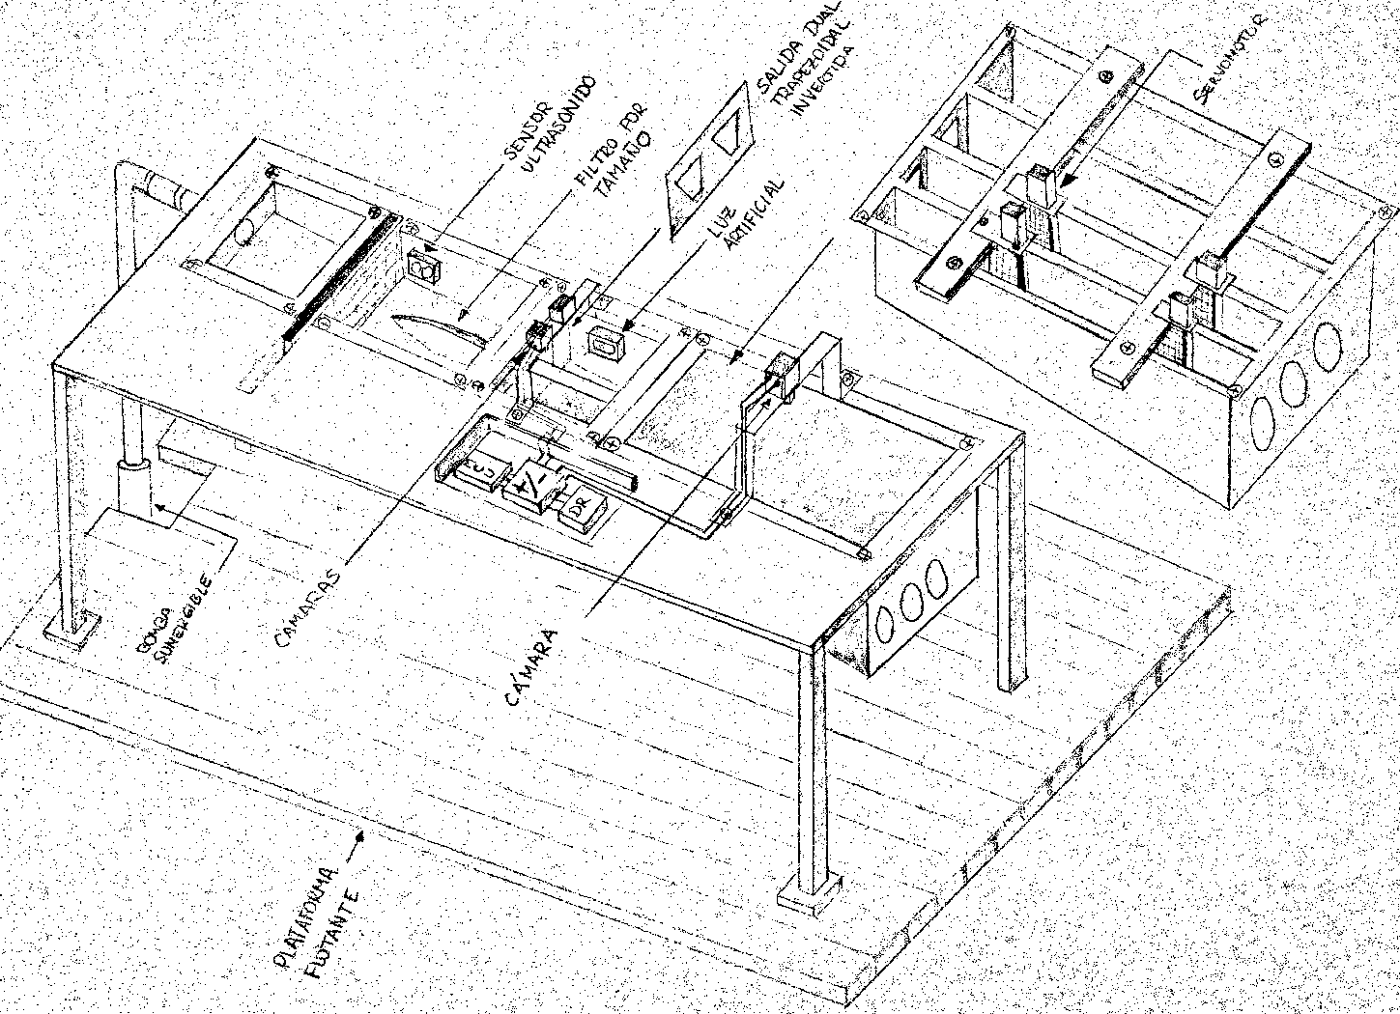
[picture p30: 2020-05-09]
Latex/trabajo-de-investigacion-2/images/chapter3/dibujo de concepto de solucion 1.png

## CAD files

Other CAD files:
CAD-CAM-CAE/1_old_deprecated/Abrazaderas tubo transparente.ipt
CAD-CAM-CAE/1_old_deprecated/Barra LED Machine Vision.ipt
CAD-CAM-CAE/1_old_deprecated/Biblioteca/Mold Design (mm).iam
CAD-CAM-CAE/1_old_deprecated/Biblioteca/OldVersions/PUCP.0080.idw
CAD-CAM-CAE/1_old_deprecated/Biblioteca/PUCP (mm).iam
CAD-CAM-CAE/1_old_deprecated/Biblioteca/PUCP (mm).ipt
CAD-CAM-CAE/1_old_deprecated/Biblioteca/PUCP.idw
CAD-CAM-CAE/1_old_deprecated/Biblioteca/Sheet Metal (mm).ipt
CAD-CAM-CAE/1_old_deprecated/Biblioteca/Standard (mm).ipn
CAD-CAM-CAE/1_old_deprecated/Biblioteca/Weldment (ISO).iam
CAD-CAM-CAE/1_old_deprecated/Camara.ipt
CAD-CAM-CAE/1_old_deprecated/Distribuidor de truchas.ipt
CAD-CAM-CAE/1_old_deprecated/Entrada.iam
CAD-CAM-CAE/1_old_deprecated/Entrada/Frame/DIN 40x40x2.9 1581911236506.ipt
CAD-CAM-CAE/1_old_deprecated/Entrada/Frame/DIN 40x40x2.9 1581911236507.ipt
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

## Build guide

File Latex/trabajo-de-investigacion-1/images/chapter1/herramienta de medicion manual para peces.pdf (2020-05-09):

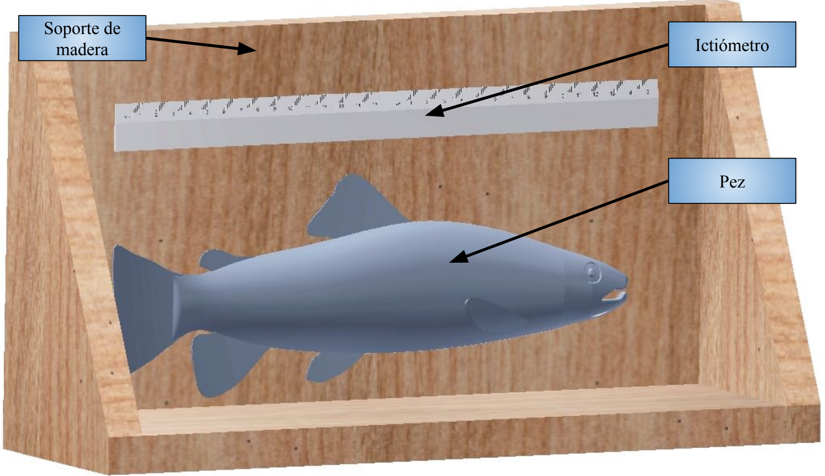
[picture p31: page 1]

Soporte de
madera | Ictiómetro

Pez

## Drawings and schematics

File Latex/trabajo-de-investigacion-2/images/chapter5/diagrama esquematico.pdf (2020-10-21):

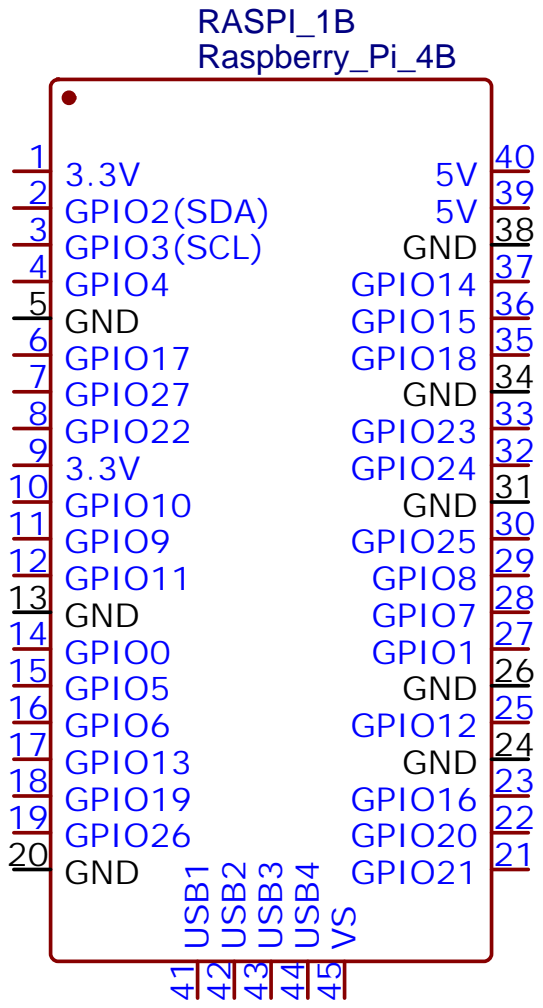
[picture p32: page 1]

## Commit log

2020-05-07 Chapter 3 is comming, before estructura de funciones
2020-05-09 chapter 3 estructura de funciones
2020-05-09 CAD added
    [Abrazaderas tubo transparente.0001.ipt, Abrazaderas tubo transparente.ipt, Barra LED Machine Vision.0020.ipt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]
2020-05-09 Chapter 3 diagrama de operaciones
2020-09-05 Tesis v2.1 + New Trabajo de investigación
2020-09-08 Tamaños de tabla mejorados
2020-09-18 Pre-imagenes + algunas descripciones
    [Abrazaderas tubo transparente.0001.ipt, Abrazaderas tubo transparente.ipt, Barra LED Machine Vision.0020.ipt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]
2020-09-23 Selección de materiales + intro + eliminar espacio luego de figuras
2020-09-26 Arquitectura de hardware + Tolva 80% + Espejos + Iluminacion
2020-09-27 Config: tamaño contenido dentro de tabla
2020-09-28 Table comparison infrared sensor finalized
2020-09-29 Stereo camera + single camera comparison 70%
2020-09-29 Datasheets added: stereo camera
2020-09-29 Datasheets: simple camera
2020-09-29 Single camera 100%
2020-09-30 Mecanismo de distribucion+ referencias+descripciones+comparacion+imagenes
2020-10-02 Arquitectura de hardware definitiva
2020-10-02 Imagenes de microprocesadores, camara simple
2020-10-02 Mecanismo distribucion de truchas cambiado de index
2020-10-05 Config: intento fallido de eliminar margenes toc
2020-10-05 Reorganización, más charts agregados, calculo de potencia formato
2020-10-05 Datasheets: LEDs de alta potencia
2020-10-05 Datasheets Motor a pasos 1
2020-10-05 indicador sonoro + indicador visual + arqutiectura de hardware
2020-10-21 Fig. Sensores de presion
2020-10-21 Fig. motores a pasos
2020-10-21 Fig. Interruptores de seguridad de apagado de emergencia
2020-10-21 Fig. Fuentes de alimentación
2020-10-21 Fig. convertidor de voltaje de conmutación
2020-10-21 Datasheets: sens presion, electrovalvulas, motores a pasos, interruptores, fuentes, convertidores
2020-10-21 Fig. Arquitectura de Hardware
2020-10-21 Diagramas de control lazo cerrado
2020-10-21 Fig. Diagrama de Flujo
2020-10-21 Diagrama de tuberias & moody
2020-10-21 Fig. Driver de motor a pasos
2020-10-21 Fig. Calculo de torque necesario
2020-10-21 Fig. Diagrama de componentes electrónicos
2020-10-21 Big Update: Cambio de configuraciones en documento por caracteristicas requeridas
2020-10-21 Datasheet: Interruptor de suministro
2020-10-21 Fig. Diagramas de control
2020-10-21 Fig. interruptor suministro
2020-10-23 Datasheet: drenador material
2020-10-23 Datasheet: leds de alta potencia
2020-10-23 Datasheet: Mosfet de activación
2020-10-23 Datasheet: indicador visual led
2020-11-06 Datasheet: Bomba de agua D03U-DK004X4
2020-11-23 Big update
    Anexos, caapitulos, configuracion, recomendaciones, conclusiones, arquitectura frames, algoritmo, distribuidora, vision total, isometrico,
2020-11-24 Trabajo de investigación 1, fixed "Nombre de Facultad"
2020-12-19 Some reports, new images, changing name old idw iam ipt
    [Abrazaderas tubo transparente.0001.ipt, Abrazaderas tubo transparente.ipt, Barra LED Machine Vision.0020.ipt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]
